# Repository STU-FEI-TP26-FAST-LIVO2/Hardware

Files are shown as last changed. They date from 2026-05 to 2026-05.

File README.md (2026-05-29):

# TP-Hardware

[Repo link](https://github.com/STU-FEI-TP26-FAST-LIVO2/Hardware-Mechanical)

> SK Verzia

Mechanická časť hardvéru<br>
[Datasheets](parameters_datasheets/)<br>
[.step súbory](printable/step/)<br>
[.stl súbory](printable/stl/)<br>
[Technické výkresy](technical_drawings/)<br>

# 3D modely konštrukčných dielov

Kompletný zoznam konštrukčných častí je uvedený nižšie. Príslušné technické výkresy sú pripojené ku každému komponentu.
Všetky rozmery potrebné k návrhu konštrukčných dielov boli prevzaté z údajových listov jednotlivých komponentov, ktoré sú uložené [tu](parameters_datasheets/).
[LiDAR](https://www.hesaitech.com/wp-content/uploads/2025/04/PandarXT-16_User_Manual_X02-en-250410.pdf)
[Kamera](https://docs.baslerweb.com/a2a1920-160ucpro)
[IMU](https://product.tdk.com/system/files/dam/doc/product/sensor/mortion-inertial/imu/data_sheet/ds-000330_icm-40609-d_v1.2.pdf)
[Jetson download center](https://developer.nvidia.com/embedded/downloads#?tx=$product,jetson_agx_orin)

## sensors_module_top

[Technický výkres](technical_drawings/sensors_modul_top_drawing.pdf)

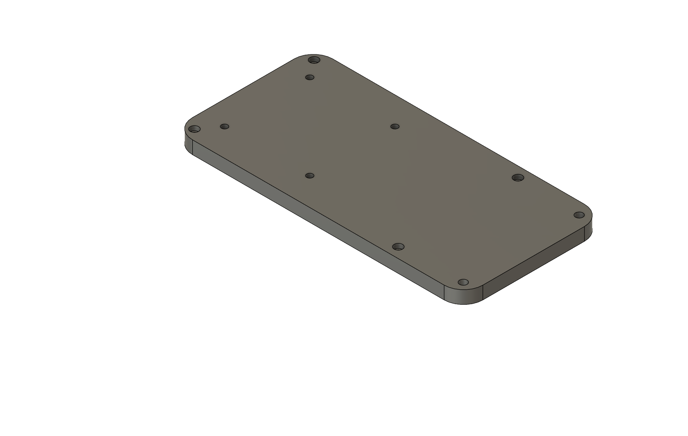
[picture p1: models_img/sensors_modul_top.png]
sensors_module_top


## sensors_module_bottom

[Technický výkres](technical_drawings/sensors_module_bottom_drawing.pdf)

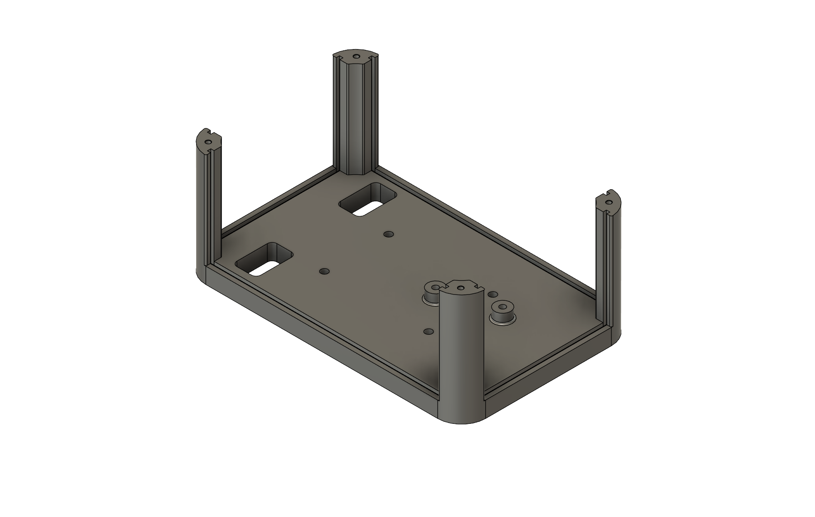
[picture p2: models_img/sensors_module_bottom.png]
sensors_module_bottom


## sm_wall_back

[Technický výkres](technical_drawings/sm_wall_back_drawing.pdf)

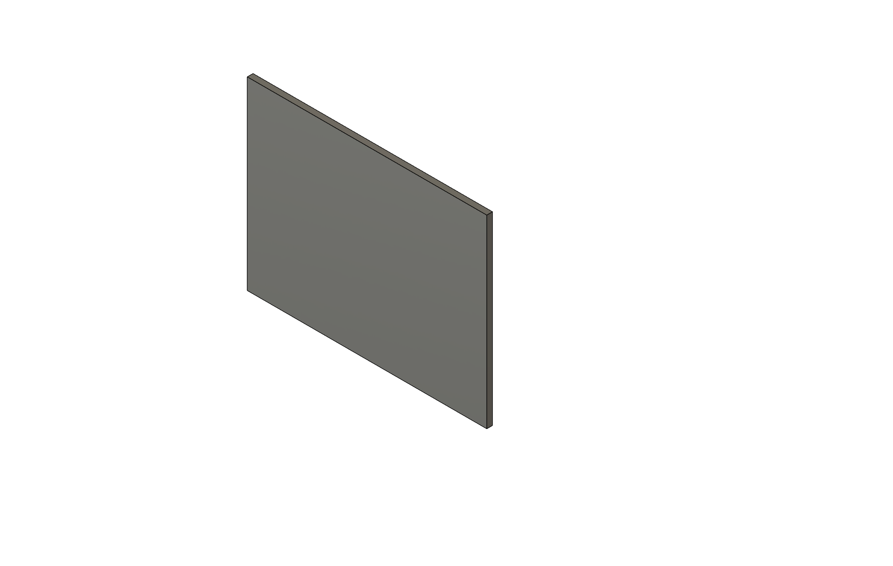
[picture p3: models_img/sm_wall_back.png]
sm_wall_back


## sm_wall_front

[Technický výkres](technical_drawings/sm_wall_front_drawing.pdf)

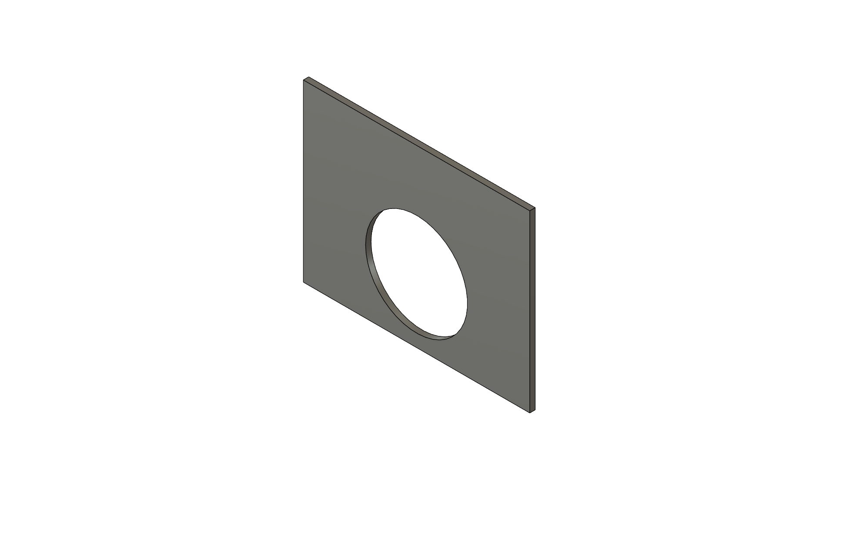
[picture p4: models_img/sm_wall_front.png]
sm_wall_front


## sm_wall_side

[Technický výkres](technical_drawings/sm_wall_side_drawing.pdf)

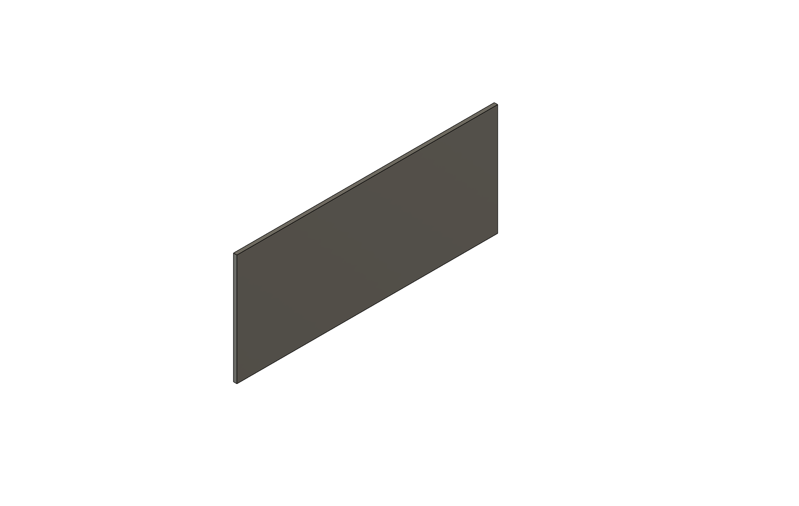
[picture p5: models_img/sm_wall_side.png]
sm_wall_side


## acu_jetson_case

[Technický výkres](technical_drawings/acu_jetson_case_drawing.pdf)

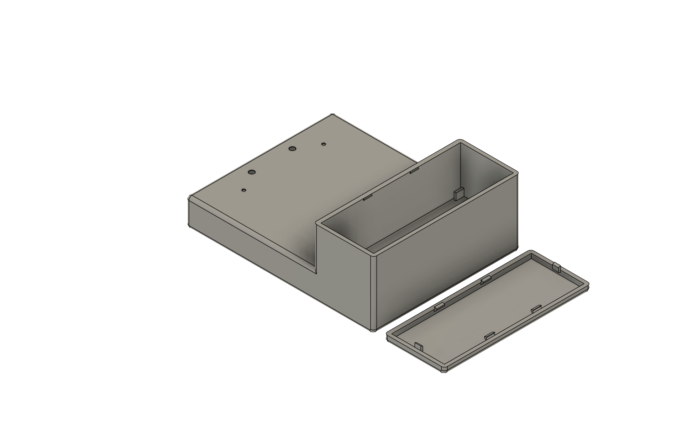
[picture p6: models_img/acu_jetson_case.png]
acu_jetson_case


## handles

[Technický výkres](technical_drawings/handles_drawing.pdf)

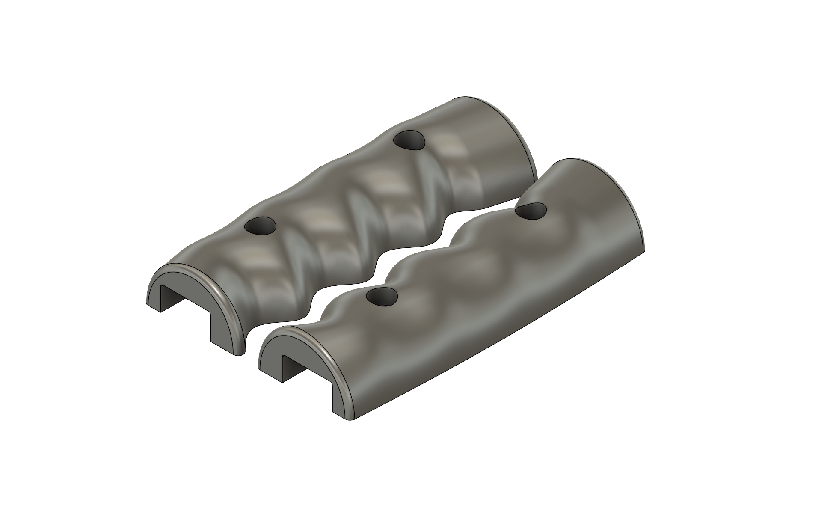
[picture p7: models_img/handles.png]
handles


# Spojovací materiál — Zoznam

| #  | Spojovací materiál | Typ | Počet |
| -- | --- | --- | ----- |
| 1  | Zápustná skrutka JIS B 1111 - M5x6 - H Steel 4.6 Plain | Skrutka | 8 |
| 2  | Zápustná skrutka JIS B 1111 - M5x30 H Steel 4.6 Plain | Skrutka | 4 |
| 3  | Šesťhranná matica DIN 934 - M5 x 0.8 Steel 6 Plain | Matica  | 8 |
| 4  | Zápustná skrutka JIS B 1111 - M5x20 H Steel 4.6 Plain | Skrutka | 4 |
| 5  | Skrutka s valcovou hlavou a vnútorným šesťhranom DIN 912 - M5 x 0.8 x 6 Steel 4.6 Plain  | Skrutka | 4 |
| 6  | Skrutka s valcovou hlavou a vnútorným šesťhranom DIN 912 - M3 x 0.5 x 10 Steel 4.6 Plain | Skrutka | 7 |
| 7  | Skrutka s valcovou hlavou a vnútorným šesťhranom DIN 912 - M3 x 0.5 x 12 Steel 4.6 Plain | Skrutka | 4 |
| 8  | Skrutka s valcovou hlavou a vnútorným šesťhranom DIN 912 - M4 x 0.7 x 16 Steel 4.6 Plain | Skrutka | 4 |
| 9  | Šesťhranná matica DIN 934 - M2.5 x 0.45 | Matica  | 8 |
| 10 | Závitová tyč DIN 976-1 - M2.5 x 85 - A | Stĺpik  | 4 |
| 11 | Závitový čap DIN 938 - M3 x 30 Steel 4.6 Plain/M2.5 | Stĺpik  | 4 |
| 12 | Šesťhranná matica DIN EN 24032 - M3 Steel 6 Plain | Matica  | 4 |
| 13 | DIN 912 - M5 x 0.8 x 10 Steel 4.6 Plain | Skrutka | 2 |
| 14 | T-matica M5 | Matica  | 8 |

**Celkový počet spojovacích prvkov: 73**

## Súhrn podľa častí, ktoré sú spojené

### Nosná konštrukcia (alu_profile / alu_profile_Lko)

| Spojovací materiál | Typ | Počet | Spája |
| --- | --- | ----- | --- |
| Zápustná skrutka JIS B 1111 - M5x6 | Skrutka | 8 | alu_profile_Lko ↔ alu_profile cez kamienok_profile |

### Senzorový modul (sensors_module_bottom / sm_wall_back / sm_wall_front / sm_wall_back / sensors_modul_top)

| Spojovací materiál | Typ | Počet | Spája |
| --- | --- | ----- | --- |
| Skrutka s vnútorným šesťhranom DIN 912 - M3x12 | Skrutka | 4 | sensors_module_bottom_v2 ↔ sensors_module_top |
| Skrutka s vnútorným šesťhranom DIN 912 - M3x10 | Skrutka | 4 | PCB_with_IMU ↔ sensors_modul_top_v3 |
| Skrutka s vnútorným šesťhranom DIN 912 - M3x10 | Skrutka | 3 | camera ↔ sensors_module_bottom_v2 |
| Zápustná skrutka JIS B 1111 - M5x20 | Skrutka | 4 | sensors_module_bottom_v2 ↔ alu_profile_Lko |
| Šesťhranná matica DIN 934 - M5 x 0.8 | Matica  | 4 | Použité s vyššie uvedenými M5 skrutkami |
| Skrutka s vnútorným šesťhranom DIN 912 - M4x16 | Skrutka | 4 | LiDAR ↔ sensors_module_top |

### Baterka / Jetson modul (acu_jetson_case)

| Spojovací materiál | Typ | Počet | Spája |
| --- | --- | ----- | --- |
| Zápustná skrutka JIS B 1111 - M5x30 | Skrutka | 4 | alu_profile_Lko ↔ acu_jetson_case |
| Šesťhranná matica DIN 934 - M5 x 0.8 | Matica  | 4 | Použité s vyššie uvedenými M5 skrutkami  |
| Závitová tyč DIN 976-1 - M2.5 x 85 - A  | Stĺpik  | 4 | acu_jetson_case ↔ jetson_agx_orin_model  |
| Šesťhranná matica DIN 934 - M2.5 x 0.45 | Matica  | 8 | acu_jetson_case & vyššie uvedené stĺpiky |

### Rukoväte

| Spojovací materiál | Typ | Počet | Spája |
| --- | --- | ----- | --- |
| Skrutka s vnútorným šesťhranom DIN 912 - M5x6 | Skrutka | 4 | handles ↔ alu_profile |

### Jetson AGX Orin Podzostava (jetson_agx_orin_model)

| Spojovací materiál | Typ | Počet | Spája |
| --- | --- | ----- | --- |
| Závitový čap DIN 938 - M3x30 | Stĺpik | 4 | jetson_agx_orin_model ↔ stlpik (stĺpiky) |
| Šesťhranná matica DIN EN 24032 - M3 | Matica | 4 | Párované s M3 stĺpikmi → uchytenie stĺpika |

### Komunikačné rozhranie LiDARu

| Spojovací materiál | Typ | Počet | Spája |
| --- | --- | ----- | --- |
| DIN 912 - M5 x 0.8 x 10 Steel 4.6 Plain | Skrutka | 2 | connection_box ↔ sensors_module_top |

# Extrinzické kalibrácie senzorov

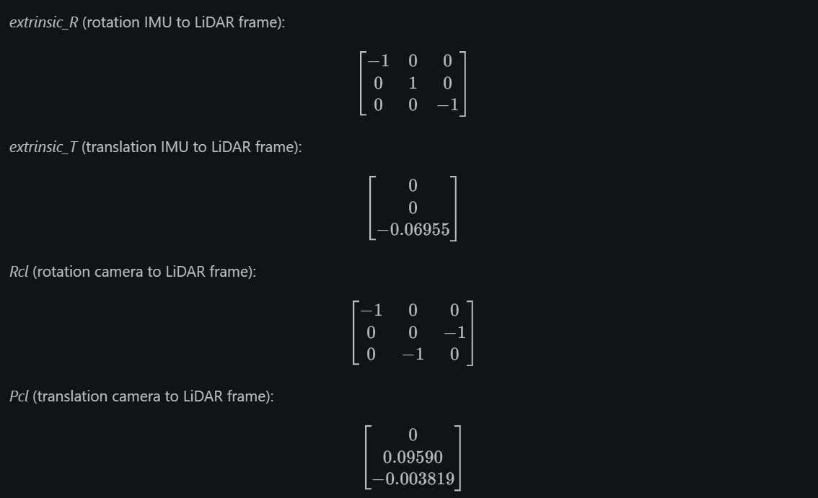
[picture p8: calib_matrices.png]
calib


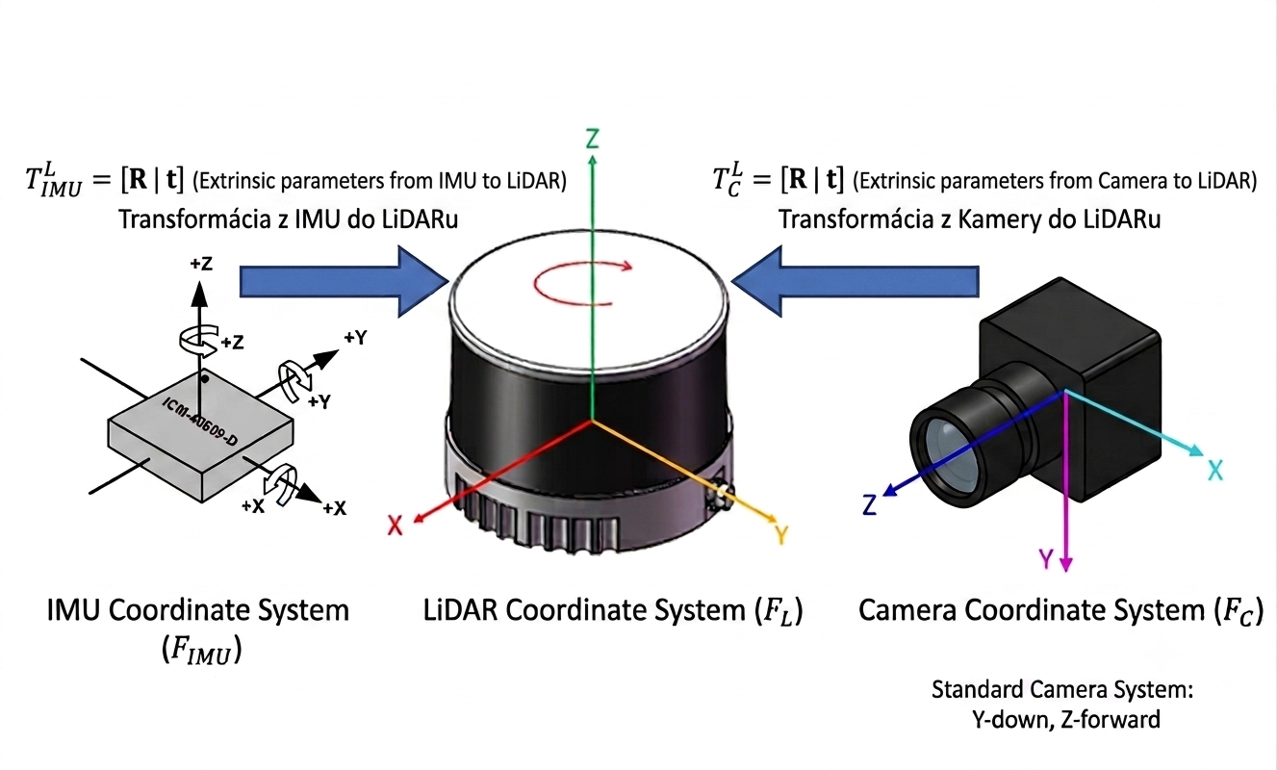
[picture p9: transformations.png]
sensoric transformations transformations


# Kompletná Zostava

## Konštrukčné časti:

* `acu_jetson_case` - modul pre Jetson a batériu
* `handles` - rukoväte pre jednoduché uchopenie
* `alu_profile` - nosná časť celej konštrukcie
* `alu_profile_Lko` - L držiak
* `sensors_module_bottom` - spodná časť senzorového modulu
* `sensors_module_top` - horná časť senzorového modulu
* `sm_wall_side` x2, `sm_wall_back`, `sm_wall_front` - steny senzorového modulu s estetickou funkciou
* `alu_profile2` x2 - stojan senzorového modulu

## Elektrické komponenty:

* LiDAR Hesai XT16
* IMU ICM-40609-D
* Kamera Basler a2A 1920 - 160uc PRO so 6 mm C-mount objektívom
* Jetson AGX Orin 64GB Developer Kit
* Acu Amewi Li-Pol 5500mAh/14,8V
* STM32 F103 Bluepill
* TTL/RS232 prevodník

## Izometrický pohľad kompletnej zostavy

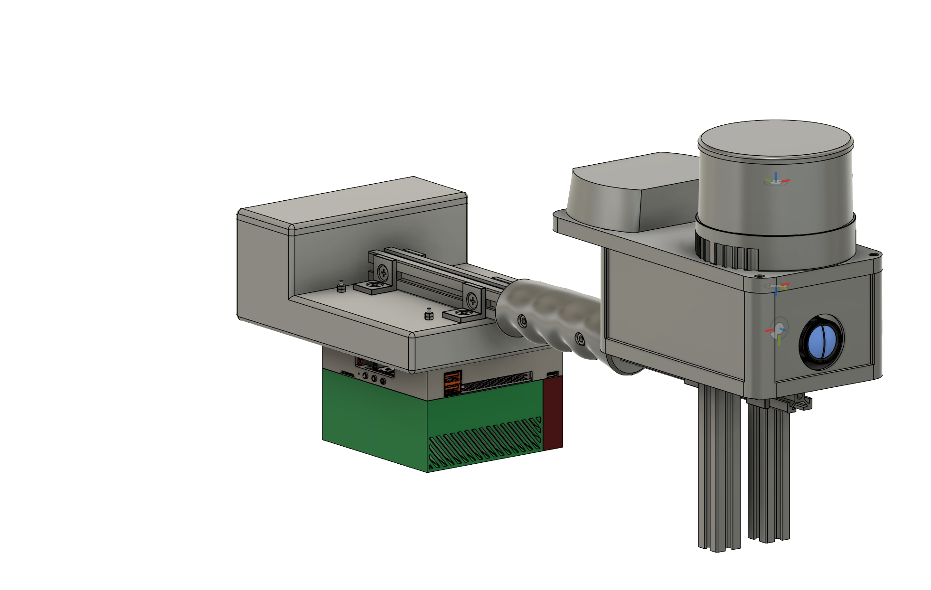
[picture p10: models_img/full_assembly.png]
full_assembly


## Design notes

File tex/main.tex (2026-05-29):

%-----------------------------------------------------------
Moja práca na hardvérovej časti tímového projektu -- návrh
\textit{mechanickej konštrukcie} a \textit{geometrický vzťah medzi
referenčnými rámcami senzorov}

%-----------------------------------------------------------
\section{Hardvérové komponenty a ich úloha}
Platforma integruje tri senzorické zariadenia, výpočtovú jednotku, a~mikroelektroniku
zabezpečujúcu komunikáciu, mechanicky zviazané do
jedného tuhého celku pomocou hliníkového profilu a~3D-tlačených konštrukčných dielov:

\begin{itemize}
  \item \textbf{LiDAR Hesai XT16} -- primárny zdroj 3D geometrie scény (16~kanálov,
        rotujúci skener). Definuje hlavný (referenčný) súradnicový systém modulu, do
        ktorého sú ostatné senzory kalibrované.
  \item \textbf{IMU ICM-40609-D} -- 6-DoF inerciálna jednotka so známym počiatkom súradnicovej sústavy
        (akcelerometrický origin). Slúži na určenie orientácie a~pomáha pri
        synchronizácii LiDAR-ových mračien bodov.
  \item \textbf{Kamera Basler a2A 1920 - 160uc PRO} so~6\,mm C-mount objektívom -- vizuálny kanál
        pre fúziu s~LiDAR-om (textúra a ofarbenie mračna bodov).
  \item \textbf{Jetson AGX Orin 64GB} -- výpočtová jednotka, mechanicky odsadená od
        senzorického modulu (vlastný 3D-tlačený box).
  \item \textbf{Akumulátor Amewi Li-Pol 5500mAh/14,8V} -- umiestnená v boxe s~GPU, napája GPU a LiDAR.
  \item \textbf{STM32 F103 Bluepill} -- mikrokontrolér pre synchronizáciu a komunikáciu senzorov
  \item \textbf{TTL/RS232 prevodník} -- zabezpečuje komunikáciu mikrokontroléra s LiDARom

\end{itemize}

Nosnou kostrou je hliníkový profil spájaný drážkovými T-maticami a~zápustnými skrutkami M5.

%-----------------------------------------------------------
\section{3D modely a~mechanická koncepcia}
Konštrukcia bola navrhnutá tak, aby minimalizovala neurčitosti v~polohách senzorov
a~ostala vyrobiteľná na bežnej FDM tlačiarni. Senzorický modul je tvorený dvoma hlavnými dielmi:
spodná konzola s~kamerou a kotvením na profil a~vrchná časť s~otvormi pre LiDAR a jeho komunikačný box.
Bočnice (steny) uzatvárajú modul. GPU spolu s baterkou sú umiestnené v~oddelenom
boxe, ktorý je uchytený L konzolami k hliníkovému profilu, čo umožňuje
servis bez rozoberania senzorickej hlavy. \textbf{Všetky tlačené súčiastky sú z materiálu PLA}.

\begin{figure}[H]
  \centering
  % --- MIESTO PRE OBRÁZOK 1: finálna konštrukcia ---
  
  \caption{Finálna konštrukcia}
  \label{fig:assembly}
\end{figure}

Kľúčové dizajnové rozhodnutia: (i) LiDAR nad kamerou s~vertikálnym odsadením,
aby si zorné polia navzájom neclonili; (ii) IMU pripevnená na vrchnej časti senzorického modulu -- fixný
vzťah IMU--LiDAR bez pohyblivých spojení; (iii) Jetson v~samostatnom boxe mimo senzorickej
hlavy.

%-----------------------------------------------------------
\section{Transformácie medzi súradnicovými systémami}
Pre fúziu dát musí byť každé meranie
prevedené do jedného referenčného rámca -- zvolili sme \emph{LiDAR-rámec} $\mathcal{F}_L$.

\begin{figure}[H]
  \centering
  % --- MIESTO PRE OBRÁZOK 2: schéma transformácií medzi senzormi ---
  
  \caption{Transformácie medzi rámcami kamery~$\mathcal{F}_C$, IMU~$\mathcal{F}_I$
  a~LiDAR-u~$\mathcal{F}_L$.}
  \label{fig:transforms}
\end{figure}

\paragraph{IMU $\rightarrow$ LiDAR}
\[
\mathbf{R}_{LI}=\!\begin{bmatrix}-1 & 0 & 0\\ 0 & 1 & 0\\ 0 & 0 & -1\end{bmatrix}\!,
\qquad
\mathbf{t}_{LI}=\!\begin{bmatrix}0\\ 0\\ -0{,}06955\end{bmatrix}\!\text{m}.
\]
Rotácia zodpovedá otočeniu o~$180^\circ$ okolo osi~$y$ (IMU je voči LiDAR-u prevrátený
zhora-nadol). Posun je iba vo vertikále -- IMU sa nachádza pribl. 70\,mm pod
referenčným bodom LiDAR-u.

\paragraph{Kamera $\rightarrow$ LiDAR}
\[
\mathbf{R}_{LC}=\!\begin{bmatrix}-1 & 0 & 0\\ 0 & 0 & -1\\ 0 & -1 & 0\end{bmatrix}\!,
\qquad
\mathbf{t}_{LC}=\!\begin{bmatrix}0\\ 0{,}09590\\ -0{,}00382\end{bmatrix}\!\text{m}.
\]
$\mathbf{R}_{LC}$ rotuje rámec kamery na rámec LiDAR-u ($x_C\!\to\!-x_L$, $z_C\!\to\!-y_L$,
$y_C\!\to\!-z_L$); kamera je odsadená pribl. 96\,mm v osi y a~mierne posunutá o -3.819 mm v osi z.

%-----------------------------------------------------------
\section{Záver}
Výsledkom je tuhá modulárna konštrukcia geometricky fixujúca LiDAR, kameru a~IMU s~jasne
definovanou extrinsikou. Transformačné matice vychádzajú z~CAD geometrie a~vstupujú do senzorickej
fúzie.

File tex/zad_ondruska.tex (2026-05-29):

\documentclass{FEIstyle}
\usepackage{booktabs}
\usepackage{graphicx}
\usepackage{subcaption}
\usepackage{amsmath}
\usepackage{listings}
\usepackage{xcolor}

\lstset{
    language=Matlab,
    basicstyle=\ttfamily\small,
    keywordstyle=\color{blue},
    commentstyle=\color{green!60!black},
    stringstyle=\color{red},
    breaklines=true,
    frame=single
}

\addbibresource{inc/ref.bib}
\FEIauthor{Bc. Matúš Ondruška}

\FEItitle{Výstupná správa do dokumentácie}

\FEIpredmet{Tímový projekt}

\FEIdate{2025/2026}

\begin{document}

% \frontmatter

\FEIcover
\FEIcontent

\mainmatter

\include{main.tex}

% \backmatter

%% Attachment A
%\FEIappendix{Algoritmus\label{att:algorithms}}{includes/attachmentA}

\FEIbibliography
\end{document}

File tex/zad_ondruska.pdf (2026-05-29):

### SLOVENSKÁ TECHNICKÁ UNIVERZITA V BRATISLAVE

### Fakulta elektrotechniky a informatiky

# Výstupná správa do dokumentácie

### Tímový projekt

2025/2026 | Bc. Matúš Ondruška

## Obsah

1 Hardvérové komponenty a ich úloha | 3
2 3D modely a mechanická koncepcia | 3
3 Transformácie medzi súradnicovými systémami | 4
4 Záver | 5

Moja práca na hardvérovej časti tímového projektu – návrh mechanickej konštrukcie a geometrický vzťah medzi referenčnými rámcami senzorov

# 1 Hardvérové komponenty a ich úloha

Platforma integruje tri senzorické zariadenia, výpočtovú jednotku, a mikroelektroniku zabezpečujúcu komunikáciu, mechanicky zviazané do jedného tuhého celku pomocou hliníkového profilu a 3D-tlačených konštrukčných dielov:

- LiDAR Hesai XT16 – primárny zdroj 3D geometrie scény (16 kanálov, rotujúci skener). Definuje hlavný (referenčný) súradnicový systém modulu, do ktorého sú

ostatné senzory kalibrované.

- IMU ICM-40609-D – 6-DoF inerciálna jednotka so známym počiatkom súradnicovej sústavy (akcelerometrický origin). Slúži na určenie orientácie a pomáha

pri synchronizácii LiDAR-ových mračien bodov.

- Kamera Basler a2A 1920 - 160uc PRO so 6 mm C-mount objektívom – vizuálny kanál pre fúziu s LiDAR-om (textúra a ofarbenie mračna bodov).
- Jetson AGX Orin 64GB – výpočtová jednotka, mechanicky odsadená od senzorického modulu (vlastný 3D-tlačený box).
- Akumulátor Amewi Li-Pol 5500mAh/14,8V – umiestnená v boxe s GPU,

napája GPU a LiDAR.

- STM32 F103 Bluepill – mikrokontrolér pre synchronizáciu a komunikáciu senzorov
- TTL/RS232 prevodník – zabezpečuje komunikáciu mikrokontroléra s LiDARom

Nosnou kostrou je hliníkový profil spájaný drážkovými T-maticami a zápustnými skrutkami M5.

# 2 3D modely a mechanická koncepcia

Konštrukcia bola navrhnutá tak, aby minimalizovala neurčitosti v polohách senzorov a ostala vyrobiteľná na bežnej FDM tlačiarni. Senzorický modul je tvorený dvoma hlavnými dielmi: spodná konzola s kamerou a kotvením na profil a vrchná časť s otvormi pre LiDAR a jeho komunikačný box. Bočnice (steny) uzatvárajú modul. GPU spolu s baterkou sú umiestnené v oddelenom boxe, ktorý je uchytený L konzolami k hliníkovému profilu, čo umožňuje servis bez rozoberania senzorickej hlavy. Všetky tlačené súčiastky sú z materiálu PLA.

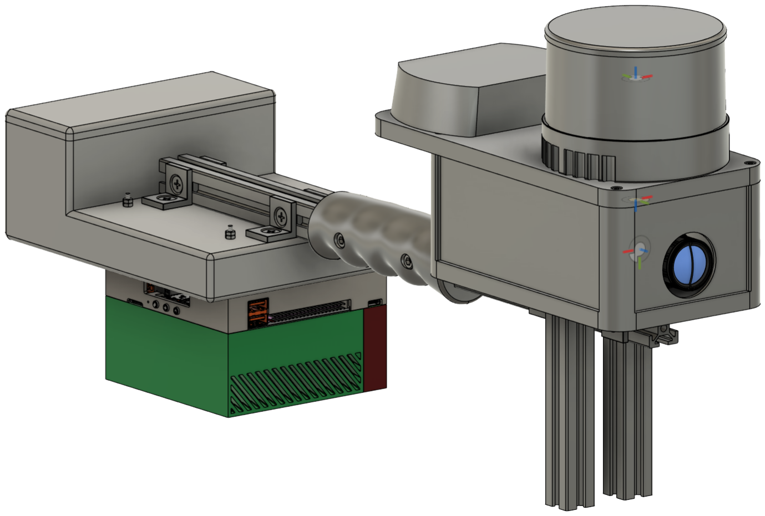
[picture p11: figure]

Obr. 1: Finálna konštrukcia

Kľúčové dizajnové rozhodnutia: (i) LiDAR nad kamerou s vertikálnym odsadením, aby si zorné polia navzájom neclonili; (ii) IMU pripevnená na vrchnej časti senzorického modulu – fixný vzťah IMU–LiDAR bez pohyblivých spojení; (iii) Jetson v samostatnom

boxe mimo senzorickej hlavy.

# 3 Transformácie medzi súradnicovými systémami

Pre fúziu dát musí byť každé meranie prevedené do jedného referenčného rámca – zvolili sme LiDAR-rámec FL.

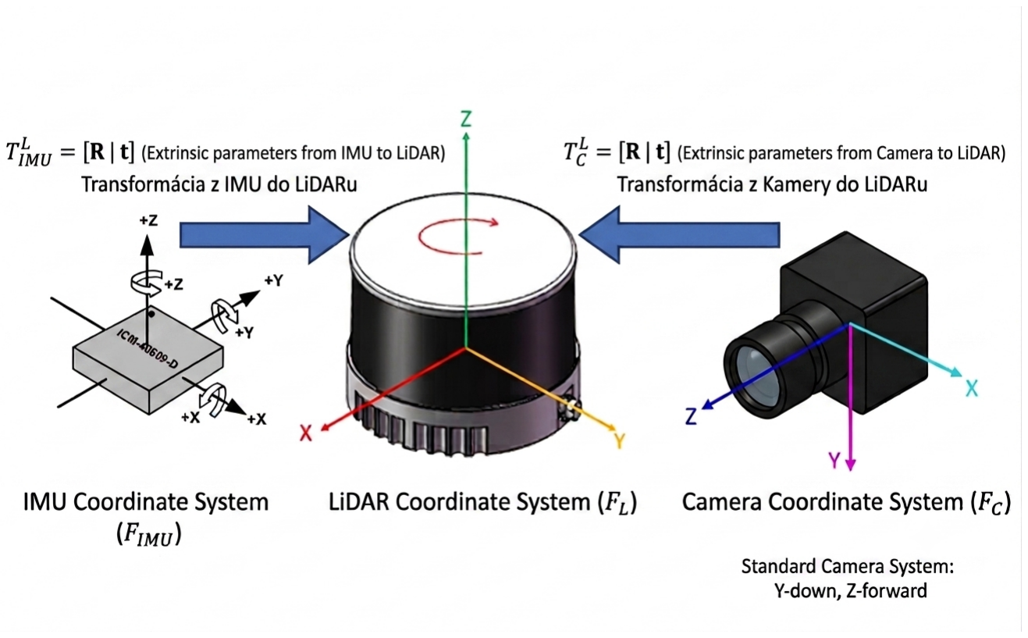
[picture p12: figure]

Obr. 2: Transformácie medzi rámcami kamery FC, IMU FI a LiDAR-u FL.

IMU → LiDAR

RLI =

−1 0 | 0
0 | 1 | 0
0 | 0 −1

, tLI =

0
0
−0,06955

m.

Rotácia zodpovedá otočeniu o 180◦ okolo osi y (IMU je voči LiDAR-u prevrátený zhora-

-nadol). Posun je iba vo vertikále – IMU sa nachádza pribl. 70 mm pod referenčným

bodom LiDAR-u.

Kamera → LiDAR

RLC =

−1 | 0 | 0
0 | 0 | −1
0 | −1 | 0

, tLC =

0
0,09590
−0,00382

m.

RLC rotuje rámec kamery na rámec LiDAR-u (xC → −xL, zC → −yL, yC → −zL);

kamera je odsadená pribl. 96 mm v osi y a mierne posunutá o -3.819 mm v osi z.

# 4 Záver

Výsledkom je tuhá modulárna konštrukcia geometricky fixujúca LiDAR, kameru a IMU s jasne definovanou extrinsikou. Transformačné matice vychádzajú z CAD geometrie a vstupujú do senzorickej fúzie.

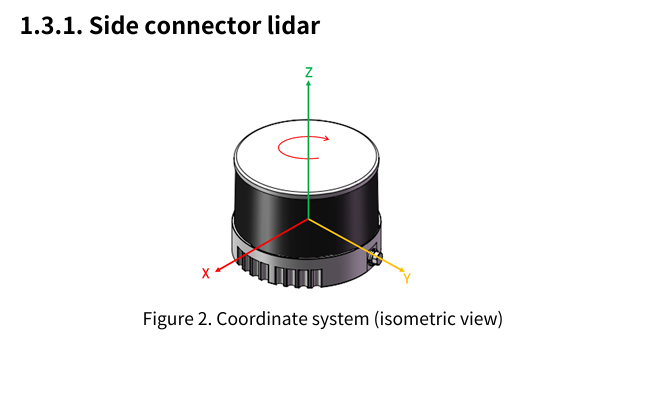
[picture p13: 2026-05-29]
parameters_datasheets/Hesai_XT16_coordinate_system.png

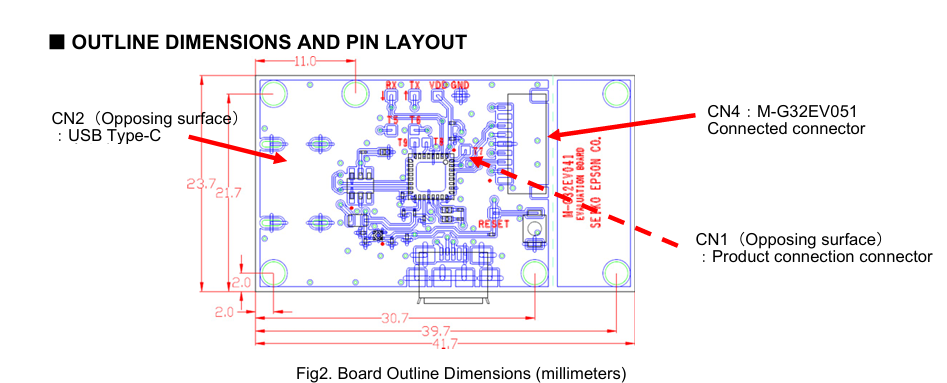
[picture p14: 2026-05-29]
parameters_datasheets/IMU_board_dimensions.png

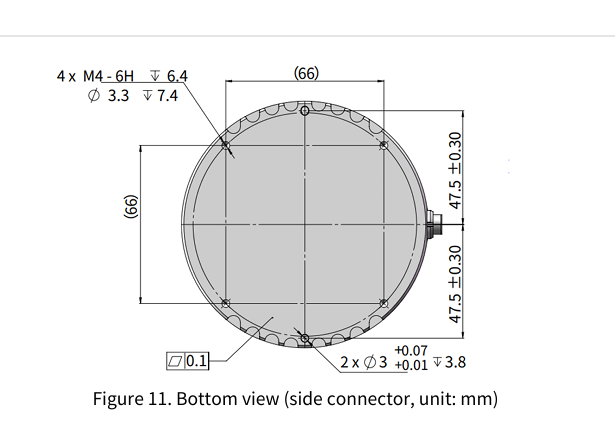
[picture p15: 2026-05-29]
parameters_datasheets/Hesai_XT16_mounting_holes.png

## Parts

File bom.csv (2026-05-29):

Part Name | full_assembly
Working BOM | as of May 4, 2026 at 11:23:04 AM UTC
Exported by | xondruskam@stuba.sk
Time of Export | 11:23 AM May 4, 2026
 | Part Number | Part Name | Revision/Version | Description | Item Number | Lifecycle | Revision | State | Quantity | Material | Change Order
 | 2026-04-16-22-42-03-118 | full_assembly |  |  |  |  |  | Working | 1
1 | 2026-04-16-22-42-56-429 | alu_profile |  |  |  |  |  | Working | 1 | Steel
2 | 2026-04-14-16-02-33-037 | handles1 |  |  |  |  |  | Working | 18 | Steel
3 | 2026-03-15-10-35-25-822 | sensors_module_bottom |  |  |  |  |  | Working | 18 | Steel
4 | DIN 934 - M5 x 0.8 Steel 6 Plain | Hexagon Nut DIN 934 - M5 x 0.8 Steel 6 Plain |  | Hexagon Nut DIN 934 - M5 x 0.8 |  |  |  | Working | 62 | Steel 6, Plain
5 | 2026-03-09-20-47-32-778 | Basler Lens 6mm C-Mount v02 |  |  |  |  |  | Working | 1 | Steel
6 | 2026-03-09-20-34-58-537 | Basler ace2 USB3 |  |  |  |  |  | Working | 18 | Generisch
7 | 2026-04-09-10-57-03-371 | sm_wall_side |  |  |  |  |  | Working | 2 | Steel
8 | 2026-04-09-10-55-33-947 | sm_wall_back |  |  |  |  |  | Working | 19 | Steel
9 | 2026-03-14-23-06-42-400 | sensors_modul_top |  |  |  |  |  | Working | 1 | Steel
10 | 2026-03-08-14-38-50-925 | Lidar |  |  |  |  |  | Working | 1 | Steel
11 | DIN 912 - M4 x 0.7 x 16 Steel 4.6 Plain | Hexagon Socket Head Cap Screw DIN 912 - M4 x 0.7 x 16 Steel 4.6 Plain |  | Hexagon Socket Head Cap Screw DIN 912 - M4 x 0.7 x 16 |  |  |  | Working | 55 | Steel 4.6, Plain
12 | DIN 912 - M3 x 0.5 x 10 Steel 4.6 Plain | Hexagon Socket Head Cap Screw DIN 912 - M3 x 0.5 x 10 Steel 4.6 Plain |  | Hexagon Socket Head Cap Screw DIN 912 - M3 x 0.5 x 10 |  |  |  | Working | 93 | Steel 4.6, Plain
13 | 2026-03-24-17-37-45-235 | BreadBord.step |  |  |  |  |  | Working | 5
13.1 | 2026-03-25-18-53-00-214 | Component1 |  |  |  |  |  | Working | 1 | Steel
13.2 | 2026-03-25-18-53-00-219 | Component2 |  |  |  |  |  | Working | 1 | Steel
14 | 2026-03-16-16-32-24-828 | 6DOF_IMU_24_Click_v100 |  | Open CASCADE Model |  |  |  | Working | 1
14.1 | 2026-03-25-19-01-00-205 | Component37 |  |  |  |  |  | Working | 1 | Steel
15 | 2026-04-24-12-49-05-410 | acu_jetson_case |  |  |  |  |  | Working | 1
15.1 | 2026-04-19-15-53-45-452 | acu |  |  |  |  |  | Working | 1 | Steel
16 | 2026-04-24-19-06-08-831 | alu_profile_Lko |  |  |  |  |  | Working | 59 | Steel
17 | CS JIS B 1111 - M5x30 - H Steel 4.6 Plain | Countersunk Screw JIS B 1111 - M5x30 H Steel 4.6 Plain |  | Countersunk Screw JIS B 1111 - M5x30 H |  |  |  | Working | 55 | Steel 4.6, Plain
18 | CS JIS B 1111 - M5x20 - H Steel 4.6 Plain | Countersunk Screw JIS B 1111 - M5x20 H Steel 4.6 Plain |  | Countersunk Screw JIS B 1111 - M5x20 H |  |  |  | Working | 55 | Steel 4.6, Plain
19 | 2026-04-26-18-56-57-064 | podstavec |  |  |  |  |  | Working | 18 | Steel
20 | 2026-04-16-22-15-38-131 | jetson_agx_orin_model |  |  |  |  |  | Working | 16
20.1 | 2026-04-16-22-15-38-141 | 600-13737-0000-A01_ASM |  | NOT SPECIFIED |  |  |  | Working | 1
20.1.1 | 2026-04-16-22-15-38-152 | LOGO_LABEL_PPID_0180X0050 |  | NOT SPECIFIED |  |  |  | Working | 1 | PTC_SYSTEM_MTRL_PROPS
20.1.2 | 2026-04-16-22-15-38-257 | 080-1638-000_2 |  | NOT SPECIFIED |  |  |  | Working | 1 | AL6061
20.1.3 | 2026-04-16-22-15-38-283 | 091-0023-000_1 |  | NOT SPECIFIED |  |  |  | Working | 1 | PTC_SYSTEM_MTRL_PROPS
20.1.4 | 2026-04-16-22-15-38-261 | 080-1665-000_1 |  | NOT SPECIFIED |  |  |  | Working | 1 | PTC_SYSTEM_MTRL_PROPS
20.1.5 | 2026-04-16-22-15-38-225 | 130-0938-000_1 |  | NOT SPECIFIED |  |  |  | Working | 1 | PTC_SYSTEM_MTRL_PROPS
20.1.6 | 2026-04-16-22-15-38-280 | 300-0494-000_1 |  | NOT SPECIFIED |  |  |  | Working | 1 | PTC_SYSTEM_MTRL_PROPS
20.1.7 | 2026-04-16-22-15-38-307 | 032-0696-000_1 |  | NOT SPECIFIED |  |  |  | Working | 4 | PTC_SYSTEM_MTRL_PROPS
20.1.8 | 2026-04-16-22-15-38-231 | 115-2921-000_1 |  | NOT SPECIFIED |  |  |  | Working | 1 | PTC_SYSTEM_MTRL_PROPS
20.1.9 | 2026-04-16-22-15-38-213 | 080-1931-000_2 |  | NOT SPECIFIED |  |  |  | Working | 2 | PTC_SYSTEM_MTRL_PROPS
20.1.10 | 2026-04-16-22-15-38-264 | 300-0402-000_1 |  | NOT SPECIFIED |  |  |  | Working | 6 | PTC_SYSTEM_MTRL_PROPS
20.1.11 | 2026-04-16-22-15-38-252 | 041-0196-000_1 |  | NOT SPECIFIED |  |  |  | Working | 2 | PTC_SYSTEM_MTRL_PROPS
20.1.12 | 2026-04-16-22-15-38-260 | 300-1096-000_1 |  | NOT SPECIFIED |  |  |  | Working | 3 | AL6061
20.1.13 | 2026-04-16-22-15-38-275 | 115-1345-000_4 |  | NOT SPECIFIED |  |  |  | Working | 3 | PTC_SYSTEM_MTRL_PROPS
20.1.14 | 2026-04-16-22-15-38-207 | 115-2489-000_1 |  | NOT SPECIFIED |  |  |  | Working | 2 | PTC_SYSTEM_MTRL_PROPS
20.1.15 | 2026-04-16-22-15-38-210 | 320-1005-000_1 |  | NOT SPECIFIED |  |  |  | Working | 4 | AL6061
20.1.16 | 2026-04-16-22-15-38-304 | 300-1070-000_3 |  | NOT SPECIFIED |  |  |  | Working | 4 | PTC_SYSTEM_MTRL_PROPS
20.1.17 | 2026-04-16-22-15-38-221 | 090-0377-000_1 |  | NOT SPECIFIED |  |  |  | Working | 1 | PTC_SYSTEM_MTRL_PROPS
20.1.18 | 2026-04-16-22-15-38-289 | 0603_H060 |  | NOT SPECIFIED |  |  |  | Working | 5 | PTC_SYSTEM_MTRL_PROPS
20.1.19 | 2026-04-16-22-15-38-222 | 080-1924-000_1 |  | NOT SPECIFIED |  |  |  | Working | 1 | PTC_SYSTEM_MTRL_PROPS
20.1.20 | 2026-04-16-22-15-38-234 | 090-0102-000_2 |  | NOT SPECIFIED |  |  |  | Working | 5 | PTC_SYSTEM_MTRL_PROPS
20.1.21 | 2026-04-16-22-15-38-216 | 080-1690-000_2 |  | NOT SPECIFIED |  |  |  | Working | 1 | PTC_SYSTEM_MTRL_PROPS
20.1.22 | 2026-04-16-22-15-38-319 | VSB_071C125D |  | NOT SPECIFIED |  |  |  | Working | 14 | PTC_SYSTEM_MTRL_PROPS
20.1.23 | 2026-04-16-22-15-38-240 | 174-0159-000_2 |  | NOT SPECIFIED |  |  |  | Working | 1 | PTC_SYSTEM_MTRL_PROPS
20.1.24 | 2026-04-16-22-15-38-249 | 0805_H140 |  | NOT SPECIFIED |  |  |  | Working | 2 | PTC_SYSTEM_MTRL_PROPS
20.1.25 | 2026-04-16-22-15-38-282 | 091-0022-000_1 |  | NOT SPECIFIED |  |  |  | Working | 2 | PTC_SYSTEM_MTRL_PROPS
20.1.26 | 2026-04-16-22-15-38-241 | IND_SMD_0402_H060 |  | NOT SPECIFIED |  |  |  | Working | 2 | PTC_SYSTEM_MTRL_PROPS
20.1.27 | 2026-04-16-22-15-38-284 | 0402_H040 |  | NOT SPECIFIED |  |  |  | Working | 427 | PTC_SYSTEM_MTRL_PROPS
20.1.28 | 2026-04-16-22-15-38-238 | 090-0296-000_2 |  | NOT SPECIFIED |  |  |  | Working | 17 | PTC_SYSTEM_MTRL_PROPS
20.1.29 | 2026-04-16-22-15-38-271 | 316-0924-000_1 |  | NOT SPECIFIED |  |  |  | Working | 1 | PTC_SYSTEM_MTRL_PROPS
20.1.30 | 2026-04-16-22-15-38-287 | 0603_H100 |  | NOT SPECIFIED |  |  |  | Working | 77 | PTC_SYSTEM_MTRL_PROPS
20.1.31 | 2026-04-16-22-15-38-296 | 115-0655-000_3 |  | NOT SPECIFIED |  |  |  | Working | 1 | PTC_SYSTEM_MTRL_PROPS
20.1.32 | 2026-04-16-22-15-38-208 | 115-3085-000_1 |  | NOT SPECIFIED |  |  |  | Working | 1 | PTC_SYSTEM_MTRL_PROPS
20.1.33 | 2026-04-16-22-15-38-258 | QFN020Q_P050_0030_T018X018 |  | NOT SPECIFIED |  |  |  | Working | 1 | AL6061
20.1.34 | 2026-04-16-22-15-38-266 | 115-2500-000_2 |  | NOT SPECIFIED |  |  |  | Working | 1 | PTC_SYSTEM_MTRL_PROPS
20.1.35 | 2026-04-16-22-15-38-219 | DFN08_P050_020X030_T016X002 |  | NOT SPECIFIED |  |  |  | Working | 1 | AL6061
20.1.36 | 2026-04-16-22-15-38-285 | 0402_H060 |  | NOT SPECIFIED |  |  |  | Working | 276 | PTC_SYSTEM_MTRL_PROPS
20.1.37 | 2026-04-16-22-15-38-247 | 0805_H150 |  | NOT SPECIFIED |  |  |  | Working | 23 | PTC_SYSTEM_MTRL_PROPS
20.1.38 | 2026-04-16-22-15-38-262 | 115-2544-000_1 |  | NOT SPECIFIED |  |  |  | Working | 3 | PTC_SYSTEM_MTRL_PROPS
20.1.39 | 2026-04-16-22-15-38-273 | 115-2947-000_1 |  | NOT SPECIFIED |  |  |  | Working | 1 | PTC_SYSTEM_MTRL_PROPS
20.1.40 | 2026-04-16-22-15-38-259 | 300-0810-000_1 |  | NOT SPECIFIED |  |  |  | Working | 1 | PTC_SYSTEM_MTRL_PROPS
20.1.41 | 2026-04-16-22-15-38-229 | 080-1749-000_1 |  | NOT SPECIFIED |  |  |  | Working | 1 | PTC_SYSTEM_MTRL_PROPS
20.1.42 | 2026-04-16-22-15-38-315 | 080-1927-000_1 |  | NOT SPECIFIED |  |  |  | Working | 1 | PTC_SYSTEM_MTRL_PROPS
20.1.43 | 2026-04-16-22-15-38-288 | 0603_H070 |  | NOT SPECIFIED |  |  |  | Working | 6 | PTC_SYSTEM_MTRL_PROPS
20.1.44 | 2026-04-16-22-15-38-218 | 115-0881-000_1 |  | NOT SPECIFIED |  |  |  | Working | 1 | PTC_SYSTEM_MTRL_PROPS
20.1.45 | 2026-04-16-22-15-38-214 | 064-0535-000_2 |  | NOT SPECIFIED |  |  |  | Working | 1 | PTC_SYSTEM_MTRL_PROPS
20.1.46 | 2026-04-16-22-15-38-316 | 080-1928-000_1 |  | NOT SPECIFIED |  |  |  | Working | 1 | PTC_SYSTEM_MTRL_PROPS
20.1.47 | 2026-04-16-22-15-38-239 | 115-2189-000_2 |  | NOT SPECIFIED |  |  |  | Working | 5 | PTC_SYSTEM_MTRL_PROPS
20.1.48 | 2026-04-16-22-15-38-209 | 315-1245-000_1 |  | NOT SPECIFIED |  |  |  | Working | 2 | PTC_SYSTEM_MTRL_PROPS
20.1.49 | 2026-04-16-22-15-38-297 | 085-0365-000_1 |  | NOT SPECIFIED |  |  |  | Working | 1 | PTC_SYSTEM_MTRL_PROPS
20.1.50 | 2026-04-16-22-15-38-306 | 300-1128-000_1 |  | NOT SPECIFIED |  |  |  | Working | 1 | AL6061
20.1.51 | 2026-04-16-22-15-38-269 | 080-1489-000_3 |  | NOT SPECIFIED |  |  |  | Working | 1 | PTC_SYSTEM_MTRL_PROPS
20.1.52 | 2026-04-16-22-15-38-292 | 115-1921-000_3 |  | NOT SPECIFIED |  |  |  | Working | 4 | AL6061
20.1.53 | 2026-04-16-22-15-38-233 | 080-1761-000_1 |  | NOT SPECIFIED |  |  |  | Working | 1 | PTC_SYSTEM_MTRL_PROPS
20.1.54 | 2026-04-16-22-15-38-300 | 086-0282-000_1 |  | NOT SPECIFIED |  |  |  | Working | 2 | PTC_SYSTEM_MTRL_PROPS
20.1.55 | 2026-04-16-22-15-38-150 | 600-13737-0000-A01 |  | NOT SPECIFIED |  |  |  | Working | 1 | Steel
20.1.56 | 2026-04-16-22-15-38-256 | 131-0134-000_4 |  | NOT SPECIFIED |  |  |  | Working | 1 | PTC_SYSTEM_MTRL_PROPS
20.1.57 | 2026-04-16-22-15-38-227 | 316-0703-000_1 |  | NOT SPECIFIED |  |  |  | Working | 3 | AL6061
20.1.58 | 2026-04-16-22-15-38-245 | 090-0134-000_2 |  | NOT SPECIFIED |  |  |  | Working | 13 | PTC_SYSTEM_MTRL_PROPS
20.1.59 | 2026-04-16-22-15-38-263 | 300-0662-000_1 |  | NOT SPECIFIED |  |  |  | Working | 8 | PTC_SYSTEM_MTRL_PROPS
20.1.60 | 2026-04-16-22-15-38-154 | 130-1575-000_1 |  | NOT SPECIFIED |  |  |  | Working | 1 | AL6061
20.1.61 | 2026-04-16-22-15-38-272 | 115-0085-000_1 |  | NOT SPECIFIED |  |  |  | Working | 1 | PTC_SYSTEM_MTRL_PROPS
20.1.62 | 2026-04-16-22-15-38-224 | 091-0080-000_1 |  | NOT SPECIFIED |  |  |  | Working | 1 | PTC_SYSTEM_MTRL_PROPS
20.1.63 | 2026-04-16-22-15-38-320 | VST_071C125D |  | NOT SPECIFIED |  |  |  | Working | 13 | PTC_SYSTEM_MTRL_PROPS
20.1.64 | 2026-04-16-22-15-38-312 | SO08_048X038 |  | NOT SPECIFIED |  |  |  | Working | 1 | PTC_SYSTEM_MTRL_PROPS
20.1.65 | 2026-04-16-22-15-38-246 | 0805_H160 |  | NOT SPECIFIED |  |  |  | Working | 20 | PTC_SYSTEM_MTRL_PROPS
20.1.66 | 2026-04-16-22-15-38-277 | 115-2514-000_1 |  | NOT SPECIFIED |  |  |  | Working | 1 | PTC_SYSTEM_MTRL_PROPS
20.1.67 | 2026-04-16-22-15-38-244 | 316-0314-000_1 |  | NOT SPECIFIED |  |  |  | Working | 2 | PTC_SYSTEM_MTRL_PROPS
20.1.68 | 2026-04-16-22-15-38-299 | 130-1221-000_1 |  | NOT SPECIFIED |  |  |  | Working | 3 | PTC_SYSTEM_MTRL_PROPS
20.1.69 | 2026-04-16-22-15-38-309 | 080-1923-000_1 |  | NOT SPECIFIED |  |  |  | Working | 1 | PTC_SYSTEM_MTRL_PROPS
20.1.70 | 2026-04-16-22-15-38-279 | 300-0381-000_1 |  | NOT SPECIFIED |  |  |  | Working | 3 | PTC_SYSTEM_MTRL_PROPS
20.1.71 | 2026-04-16-22-15-38-302 | 280-0161-000_1 |  | NOT SPECIFIED |  |  |  | Working | 3 | PTC_SYSTEM_MTRL_PROPS
20.1.72 | 2026-04-16-22-15-38-237 | 115-2766-000_1 |  | NOT SPECIFIED |  |  |  | Working | 2 | PTC_SYSTEM_MTRL_PROPS
20.1.73 | 2026-04-16-22-15-38-305 | 300-0817-000_2 |  | NOT SPECIFIED |  |  |  | Working | 6 | PTC_SYSTEM_MTRL_PROPS
20.1.74 | 2026-04-16-22-15-38-236 | LTPT071C125D |  | NOT SPECIFIED |  |  |  | Working | 124 | PTC_SYSTEM_MTRL_PROPS
20.1.75 | 2026-04-16-22-15-38-220 | 090-0378-000_1 |  | NOT SPECIFIED |  |  |  | Working | 3 | AL6061
20.1.76 | 2026-04-16-22-15-38-254 | 092-0241-000_1 |  | NOT SPECIFIED |  |  |  | Working | 1 | PTC_SYSTEM_MTRL_PROPS
20.1.77 | 2026-04-16-22-15-38-211 | 155-1175-000_1 |  | NOT SPECIFIED |  |  |  | Working | 3 | AL6061
20.1.78 | 2026-04-16-22-15-38-311 | 315-1257-000_1 |  | NOT SPECIFIED |  |  |  | Working | 1 | PTC_SYSTEM_MTRL_PROPS
20.1.79 | 2026-04-16-22-15-38-232 | 1206_H180 |  | NOT SPECIFIED |  |  |  | Working | 7 | PTC_SYSTEM_MTRL_PROPS
20.1.80 | 2026-04-16-22-15-38-235 | 090-0367-000_1 |  | NOT SPECIFIED |  |  |  | Working | 5 | PTC_SYSTEM_MTRL_PROPS
20.1.81 | 2026-04-16-22-15-38-310 | 080-1898-000_1 |  | NOT SPECIFIED |  |  |  | Working | 1 | PTC_SYSTEM_MTRL_PROPS
20.1.82 | 2026-04-16-22-15-38-151 | 065-0738-000_1 |  | NOT SPECIFIED |  |  |  | Working | 2 | PTC_SYSTEM_MTRL_PROPS
20.1.83 | 2026-04-16-22-15-38-314 | 064-0531-000_1 |  | NOT SPECIFIED |  |  |  | Working | 1 | PTC_SYSTEM_MTRL_PROPS
20.1.84 | 2026-04-16-22-15-38-291 | 300-1074-000_1 |  | NOT SPECIFIED |  |  |  | Working | 2 | PTC_SYSTEM_MTRL_PROPS
20.1.85 | 2026-04-16-22-15-38-281 | 300-0485-000_2 |  | NOT SPECIFIED |  |  |  | Working | 17 | PTC_SYSTEM_MTRL_PROPS
20.1.86 | 2026-04-16-22-15-38-298 | 115-2752-000_1 |  | NOT SPECIFIED |  |  |  | Working | 1 | AL6061
20.1.87 | 2026-04-16-22-15-38-230 | IND_SMD_0805_H110 |  | NOT SPECIFIED |  |  |  | Working | 2 | PTC_SYSTEM_MTRL_PROPS
20.1.88 | 2026-04-16-22-15-38-253 | LOGO_SILK_WEEE_0485X0683 |  | NOT SPECIFIED |  |  |  | Working | 1 | PTC_SYSTEM_MTRL_PROPS
20.1.89 | 2026-04-16-22-15-38-295 | 115-2838-000_1 |  | NOT SPECIFIED |  |  |  | Working | 1 | PTC_SYSTEM_MTRL_PROPS
20.1.90 | 2026-04-16-22-15-38-270 | 080-1346-000_3 |  | NOT SPECIFIED |  |  |  | Working | 1 | AL6061
20.1.91 | 2026-04-16-22-15-38-155 | 130-0748-000_1 |  | NOT SPECIFIED |  |  |  | Working | 1 | PTC_SYSTEM_MTRL_PROPS
20.1.92 | 2026-04-16-22-15-38-308 | LOGO_SILK_NVIDIA_I0600X0330 |  | NOT SPECIFIED |  |  |  | Working | 1 | PTC_SYSTEM_MTRL_PROPS
20.1.93 | 2026-04-16-22-15-38-223 | 115-2054-000_1 |  | NOT SPECIFIED |  |  |  | Working | 1 | PTC_SYSTEM_MTRL_PROPS
20.1.94 | 2026-04-16-22-15-38-215 | 215-0379-000_1 |  | NOT SPECIFIED |  |  |  | Working | 2 | AL6061
20.1.95 | 2026-04-16-22-15-38-267 | 115-2146-000_1 |  | NOT SPECIFIED |  |  |  | Working | 1 | PTC_SYSTEM_MTRL_PROPS
20.1.96 | 2026-04-16-22-15-38-318 | LOGO_SILK_180_I560 |  | NOT SPECIFIED |  |  |  | Working | 1 | PTC_SYSTEM_MTRL_PROPS
20.1.97 | 2026-04-16-22-15-38-290 | 300-0992-000_2 |  | NOT SPECIFIED |  |  |  | Working | 2 | AL6061
20.1.98 | 2026-04-16-22-15-38-265 | 115-1680-000_1 |  | NOT SPECIFIED |  |  |  | Working | 4 | PTC_SYSTEM_MTRL_PROPS
20.1.99 | 2026-04-16-22-15-38-268 | 315-1235-000_1 |  | NOT SPECIFIED |  |  |  | Working | 1 | PTC_SYSTEM_MTRL_PROPS
20.1.100 | 2026-04-16-22-15-38-317 | 080-1926-000_3 |  | NOT SPECIFIED |  |  |  | Working | 1 | PTC_SYSTEM_MTRL_PROPS
20.1.101 | 2026-04-16-22-15-38-274 | 115-1426-000_1 |  | NOT SPECIFIED |  |  |  | Working | 3 | PTC_SYSTEM_MTRL_PROPS
20.1.102 | 2026-04-16-22-15-38-276 | 115-1821-000_1 |  | NOT SPECIFIED |  |  |  | Working | 5 | PTC_SYSTEM_MTRL_PROPS
20.1.103 | 2026-04-16-22-15-38-278 | 115-0138-000_1 |  | NOT SPECIFIED |  |  |  | Working | 1 | PTC_SYSTEM_MTRL_PROPS
20.1.104 | 2026-04-16-22-15-38-250 | 0805_H060 |  | NOT SPECIFIED |  |  |  | Working | 6 | PTC_SYSTEM_MTRL_PROPS
20.1.105 | 2026-04-16-22-15-38-226 | 316-0613-000_2 |  | NOT SPECIFIED |  |  |  | Working | 2 | PTC_SYSTEM_MTRL_PROPS
20.1.106 | 2026-04-16-22-15-38-217 | 315-1258-000_1 |  | NOT SPECIFIED |  |  |  | Working | 1 | PTC_SYSTEM_MTRL_PROPS
20.1.107 | 2026-04-16-22-15-38-313 | 086-0303-000_1 |  | NOT SPECIFIED |  |  |  | Working | 1 | PTC_SYSTEM_MTRL_PROPS
20.1.108 | 2026-04-16-22-15-38-293 | 130-0846-000_1 |  | NOT SPECIFIED |  |  |  | Working | 1 | PTC_SYSTEM_MTRL_PROPS
20.1.109 | 2026-04-16-22-15-38-248 | 0805_H070 |  | NOT SPECIFIED |  |  |  | Working | 2 | PTC_SYSTEM_MTRL_PROPS
20.1.110 | 2026-04-16-22-15-38-242 | CON_HDR_002X005_SMD_ST_M_P_GREY |  | NOT SPECIFIED |  |  |  | Working | 1 | Steel
20.1.111 | 2026-04-16-22-15-38-243 | LOGO_SILK_ROHS_D050_CHINA |  | NOT SPECIFIED |  |  |  | Working | 1 | PTC_SYSTEM_MTRL_PROPS
20.1.112 | 2026-04-16-22-15-38-255 | LOGO_SILK_HF_I0185X0120 |  | NOT SPECIFIED |  |  |  | Working | 1 | PTC_SYSTEM_MTRL_PROPS
20.1.113 | 2026-04-16-22-15-38-294 | MEC_STANDOFF_PTH_620C380P |  | NOT SPECIFIED |  |  |  | Working | 1 | PTC_SYSTEM_MTRL_PROPS
20.1.114 | 2026-04-16-22-15-38-212 | 320-0965-000_5 |  | NOT SPECIFIED |  |  |  | Working | 1 | AL6061
20.1.115 | 2026-04-16-22-15-38-251 | 032-0796-000_1 |  | NOT SPECIFIED |  |  |  | Working | 3 | PTC_SYSTEM_MTRL_PROPS
20.1.116 | 2026-04-16-22-15-38-301 | 085-0347-000_1 |  | NOT SPECIFIED |  |  |  | Working | 1 | PTC_SYSTEM_MTRL_PROPS
20.1.117 | 2026-04-16-22-15-38-228 | 315-1041-000_3 |  | NOT SPECIFIED |  |  |  | Working | 2 | AL6061
20.1.118 | 2026-04-16-22-15-38-286 | 0402_H070 |  | NOT SPECIFIED |  |  |  | Working | 3 | PTC_SYSTEM_MTRL_PROPS
20.1.119 | 2026-04-16-22-15-38-303 | QFN040Q_P050_0065_T047X047 |  | NOT SPECIFIED |  |  |  | Working | 1 | PTC_SYSTEM_MTRL_PROPS
20.1.120 | 2026-04-16-22-15-38-153 | LL_VENDOR_DATECODE_TOP_2R |  | NOT SPECIFIED |  |  |  | Working | 1 | PTC_SYSTEM_MTRL_PROPS
20.2 | 2026-04-16-22-15-38-402 | PCIE_COVER_CONCORD_ASM |  | NOT SPECIFIED |  |  |  | Working | 1
20.2.1 | 2026-04-16-22-15-38-406 | MAGNET_PCIE_CVR_CONCORD_ASSY_ASM |  | NOT SPECIFIED |  |  |  | Working | 3
20.2.1.1 | 2026-04-16-22-15-38-407 | MAGNET_PCIE_CVR_CONCORD |  | NOT SPECIFIED |  |  |  | Working | 1 | PTC_SYSTEM_MTRL_PROPS
20.2.2 | 2026-04-16-22-15-38-410 | 371-0232-000 |  | NOT SPECIFIED |  |  |  | Working | 1 | PTC_SYSTEM_MTRL_PROPS
20.2.3 | 2026-04-16-22-15-38-409 | MYLAR_MAGNET_PCIE_CVR_2 |  | NOT SPECIFIED |  |  |  | Working | 1 | PTC_SYSTEM_MTRL_PROPS
20.2.4 | 2026-04-16-22-15-38-404 | ANT-ASSEMBLY_FR4-1 |  | NOT SPECIFIED |  |  |  | Working | 1 | Steel
20.2.5 | 2026-04-16-22-15-38-408 | MYLAR_MAGNET_PCIE_CVR |  | NOT SPECIFIED |  |  |  | Working | 1 | PTC_SYSTEM_MTRL_PROPS
20.2.6 | 2026-04-16-22-15-38-405 | ANT-ASSEMBLY_FR4-2 |  | NOT SPECIFIED |  |  |  | Working | 1 | Steel
20.2.7 | 2026-04-16-22-15-38-403 | PCIE_COVER_CONCORD |  | NOT SPECIFIED |  |  |  | Working | 1 | PTC_SYSTEM_MTRL_PROPS
20.3 | 2026-04-16-22-15-38-411 | SCREW_M2_5_25_3 |  | NOT SPECIFIED |  |  |  | Working | 4 | Steel
20.4 | 2026-04-16-22-15-38-376 | 245-13701-0000-000_ASM |  | NOT SPECIFIED |  |  |  | Working | 1
20.4.1 | 2026-04-16-22-15-38-377 | 600-13701-BASE-A00_ASM |  | NOT SPECIFIED |  |  |  | Working | 1
20.4.1.1 | 2026-04-16-22-15-38-378 | 080-1502-000_4 |  | NOT SPECIFIED |  |  |  | Working | 1 | PTC_SYSTEM_MTRL_PROPS
20.4.2 | 2026-04-16-22-15-38-389 | 155-1167-000 |  | NOT SPECIFIED |  |  |  | Working | 4 | PTC_SYSTEM_MTRL_PROPS
20.4.3 | 2026-04-16-22-15-38-379 | 600-63701-BASE-A05_ASM |  | NOT SPECIFIED |  |  |  | Working | 1
20.4.3.1 | 2026-04-16-22-15-38-380 | 600-63701-BASE-A05 |  | NOT SPECIFIED |  |  |  | Working | 1 | Steel
20.4.4 | 2026-04-16-22-15-38-386 | HEATPIPE-P3701-LIDLESS |  | NOT SPECIFIED |  |  |  | Working | 2 | CU
20.4.5 | 2026-04-16-22-15-38-388 | 155-0532-000 |  | NOT SPECIFIED |  |  |  | Working | 4 | PTC_SYSTEM_MTRL_PROPS
20.4.6 | 2026-04-16-22-15-38-381 | 320-1885-000-LIDLESS_ASM |  | NOT SPECIFIED |  |  |  | Working | 1
20.4.6.1 | 2026-04-16-22-15-38-382 | 320-1885-000 |  | NOT SPECIFIED |  |  |  | Working | 1 | AL6061
20.4.6.2 | 2026-04-16-22-15-38-384 | TTP-EAST-MEM |  | NOT SPECIFIED |  |  |  | Working | 1 | CU
20.4.6.3 | 2026-04-16-22-15-38-385 | TTP-SOUTH-MEM-2 |  | NOT SPECIFIED |  |  |  | Working | 1 | CU
20.4.6.4 | 2026-04-16-22-15-38-383 | SPREADER-P3701-LIDLESS |  | NOT SPECIFIED |  |  |  | Working | 1 | CU
20.4.7 | 2026-04-16-22-15-38-387 | 367-0600-000A |  | NOT SPECIFIED |  |  |  | Working | 1 | PTC_SYSTEM_MTRL_PROPS
20.5 | 2026-04-16-22-15-38-400 | 330-0266-000_M2_WIFI_MODULE_ASM |  | NOT SPECIFIED |  |  |  | Working | 1
20.5.1 | 2026-04-16-22-15-38-401 | 330-0266-000_MODULE_BOARD |  | NOT SPECIFIED |  |  |  | Working | 1 | PTC_SYSTEM_MTRL_PROPS
20.6 | 2026-04-16-22-15-38-367 | FOOT_CONCCORD_ASM |  | NOT SPECIFIED |  |  |  | Working | 1
20.6.1 | 2026-04-16-22-15-38-371 | FOOT_RUBBER_CONCORD_2 |  | NOT SPECIFIED |  |  |  | Working | 1 | PTC_SYSTEM_MTRL_PROPS
20.6.2 | 2026-04-16-22-15-38-369 | FOOT_CONCORD_BUTTON_RUBBER |  | NOT SPECIFIED |  |  |  | Working | 1 | PTC_SYSTEM_MTRL_PROPS
20.6.3 | 2026-04-16-22-15-38-372 | LG-4_CONCORD_0420 |  | NOT SPECIFIED |  |  |  | Working | 1 | Steel
20.6.4 | 2026-04-16-22-15-38-373 | ADHESIVE_FOOT_COVER_CONCORD |  | NOT SPECIFIED |  |  |  | Working | 1 | PTC_SYSTEM_MTRL_PROPS
20.6.5 | 2026-04-16-22-15-38-374 | ADHESIVE_FEET_CONCORD |  | NOT SPECIFIED |  |  |  | Working | 1 | PTC_SYSTEM_MTRL_PROPS
20.6.6 | 2026-04-16-22-15-38-368 | FOOT_CONCORD |  | NOT SPECIFIED |  |  |  | Working | 1 | PTC_SYSTEM_MTRL_PROPS
20.6.7 | 2026-04-16-22-15-38-375 | ADHESIVE_FEET_CONCORD_2 |  | NOT SPECIFIED |  |  |  | Working | 1 | PTC_SYSTEM_MTRL_PROPS
20.6.8 | 2026-04-16-22-15-38-370 | FOOT_RUBBER_CONCORD |  | NOT SPECIFIED |  |  |  | Working | 1 | PTC_SYSTEM_MTRL_PROPS
20.7 | 2026-04-16-22-15-38-390 | FANSINK_CONCORD_ASM |  | NOT SPECIFIED |  |  |  | Working | 1
20.7.1 | 2026-04-16-22-15-38-391 | FAN_COVER_CONCORD_COLLAPSIBLE |  | NOT SPECIFIED |  |  |  | Working | 1 | PTC_SYSTEM_MTRL_PROPS
20.7.2 | 2026-04-16-22-15-38-397 | GALEN_FAN_WIRE_SCREW |  | NOT SPECIFIED |  |  |  | Working | 1 | PTC_SYSTEM_MTRL_PROPS
20.7.3 | 2026-04-16-22-15-38-399 | CONCORD_FAN_SCREW |  | NOT SPECIFIED |  |  |  | Working | 3 | PTC_SYSTEM_MTRL_PROPS
20.7.4 | 2026-04-16-22-15-38-392 | HEATSINK_CONCORD |  | NOT SPECIFIED |  |  |  | Working | 1 | PTC_SYSTEM_MTRL_PROPS
20.7.5 | 2026-04-16-22-15-38-393 | CONCORD_FAN_ASSY_ASM |  | NOT SPECIFIED |  |  |  | Working | 1
20.7.5.1 | 2026-04-16-22-15-38-394 | 7014_ASSY_ASM_CONCORD_ASM |  | NOT SPECIFIED |  |  |  | Working | 1
20.7.5.1.1 | 2026-04-16-22-15-38-396 | 7014_IMPELLER_CONCORD |  | NOT SPECIFIED |  |  |  | Working | 1 | Steel
20.7.5.1.2 | 2026-04-16-22-15-38-395 | 7013_PILLOW_CONCORD |  | NOT SPECIFIED |  |  |  | Working | 1 | Steel
20.7.6 | 2026-04-16-22-15-38-398 | MAGNET_FAN_CVR_CONCORD |  | NOT SPECIFIED |  |  |  | Working | 6 | PTC_SYSTEM_MTRL_PROPS
20.8 | 2026-05-03-00-33-30-181 | stlpik |  |  |  |  |  | Working | 4 | Steel
20.9 | DIN 938 - M3 x 30 Steel 4.6 Plain | Stud DIN 938 - M3 x 30 Steel 4.6 Plain |  | Stud DIN 938 - M3 x 30 |  |  |  | Working | 4 | Steel 4.6, Plain
20.10 | DIN EN 24032 - M3 Steel 6 Plain | Hexagon Regular Nut DIN EN 24032 - M3 Steel 6 Plain |  | Hexagon Regular Nut DIN EN 24032 - M3 |  |  |  | Working | 4 | Steel 6, Plain
21 | 2026-05-02-12-46-54-079 | kamienok_profil |  |  |  |  |  | Working | 183 | Steel
22 | FCS JIS B 1111 (H) - M5x6 Steel 4.6 Plain | Countersunk Screw JIS B 1111 - M5x6 - H Steel 4.6 Plain |  | Countersunk Screw JIS B 1111 - M5x6 - H |  |  |  | Working | 120 | Steel 4.6, Plain
23 | DIN 912 - M5 x 0.8 x 6 Steel 4.6 Plain | Hexagon Socket Head Cap Screw DIN 912 - M5 x 0.8 x 6 Steel 4.6 Plain |  | Hexagon Socket Head Cap Screw DIN 912 - M5 x 0.8 x 6 |  |  |  | Working | 58 | Steel 4.6, Plain
24 | 2026-05-02-16-00-16-861 | pcb_with_IMU |  |  |  |  |  | Working | 13
24.1 | 2026-05-02-16-00-16-862 | PCB Component |  |  |  |  |  | Working | 1
24.1.1 | 2026-05-02-16-00-16-867 | 3,2 |  |  |  |  |  | Working | 4 | Steel
24.1.2 | 2026-05-02-16-00-16-863 | Board |  |  |  |  |  | Working | 1 | Steel
24.1.3 | 2026-05-02-16-00-16-864 | 10X03MTA |  |  |  |  |  | Working | 2 | Steel
24.1.4 | 2026-05-02-16-00-16-868 | JST_B2B-XH-A |  |  |  |  |  | Working | 1 | Steel
24.1.5 | 2026-05-02-16-00-16-866 | 10X04MTA |  |  |  |  |  | Working | 1 | Steel
24.1.6 | 2026-05-02-16-00-16-870 | 1X01 |  |  |  |  |  | Working | 2 | Steel
24.1.7 | 2026-05-02-16-00-16-865 | BLUE_PILL |  |  |  |  |  | Working | 1 | Steel
24.1.8 | 2026-05-02-16-00-16-869 | 1X08 |  |  |  |  |  | Working | 2 | Steel
24.2 | 2026-03-16-16-32-24-828 | 6DOF_IMU_24_Click_v100 |  | Open CASCADE Model |  |  |  | Working | 1
24.2.1 | 2026-03-25-19-01-00-205 | Component37 |  |  |  |  |  | Working | 1 | Steel
25 | BSHCS ASME B18.3.1M - M2x0.4 x 35 Steel Grade 2 Plain | Broached Hexagon Socket Head Cap Screw ASME B18.3.1M - M2x0.4 x 35 Steel Grade 2 Plain |  | Broached Hexagon Socket Head Cap Screw ASME B18.3.1M - M2x0.4 x 35 |  |  |  | Working | 4 | Steel Grade 2, Plain
26 | DIN 433 - 2.2 Steel 100 HV Plain | Washer DIN 433-1 - 2.2 - A Steel 100 HV Plain |  | Washer DIN 433-1 - 2.2 - A |  |  |  | Working | 4 | Steel 100 HV, Plain
27 | 2026-05-03-00-33-30-181 | stlpik |  |  |  |  |  | Working | 12 | Steel
28 | BSHCS ASME B18.3.1M - M2.5x0.45 x 30 Steel Grade 2 Plain | Broached Hexagon Socket Head Cap Screw ASME B18.3.1M - M2.5x0.45 x 30 Steel Grade 2 Plain |  | Broached Hexagon Socket Head Cap Screw ASME B18.3.1M - M2.5x0.45 x 30 |  |  |  | Working | 44 | Steel Grade 2, Plain
29 | DIN 125 - A 2.2 Steel 100 HV Plain | Washer DIN 125-1 - 2.2 - A Steel 100 HV Plain |  | Washer DIN 125-1 - 2.2 - A |  |  |  | Working | 44 | Steel 100 HV, Plain
30 | 2026-05-03-14-55-16-839 | lidar_connection_box |  |  |  |  |  | Working | 6 | Steel

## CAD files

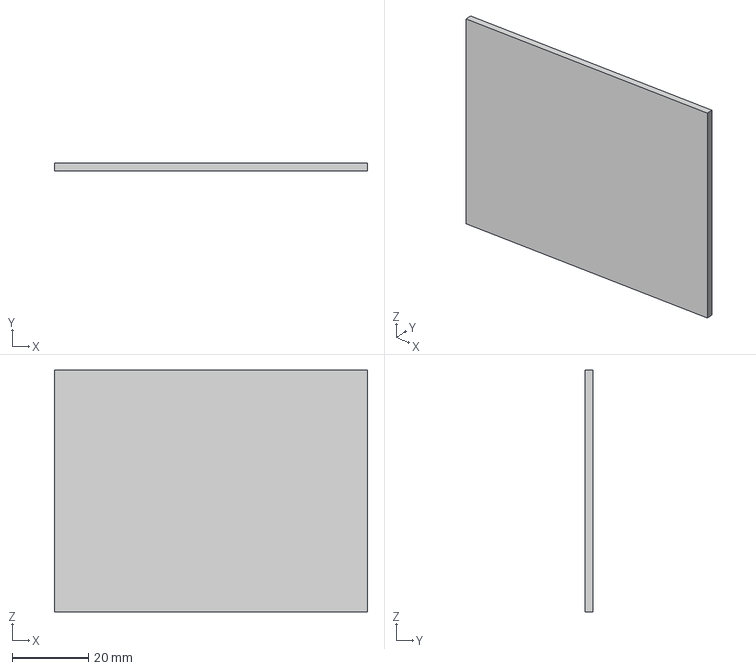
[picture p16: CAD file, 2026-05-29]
printable/step/sm_wall_back.step
82.3 x 2.00 x 63.6 mm

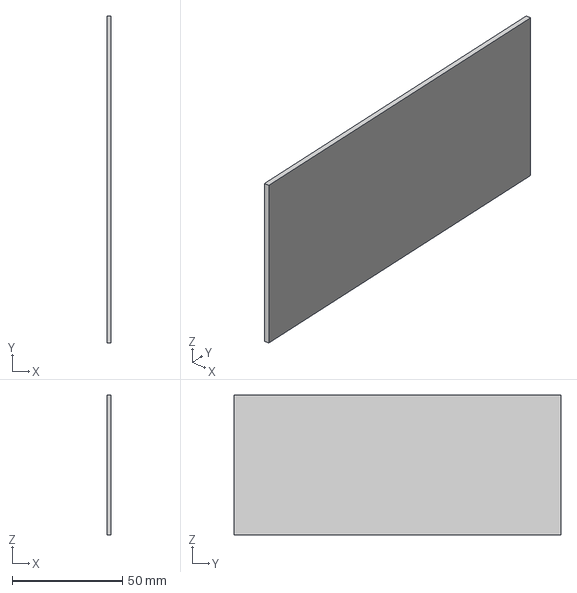
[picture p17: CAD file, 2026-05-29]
printable/step/sm_wall_side.step
2.00 x 148.6 x 63.6 mm

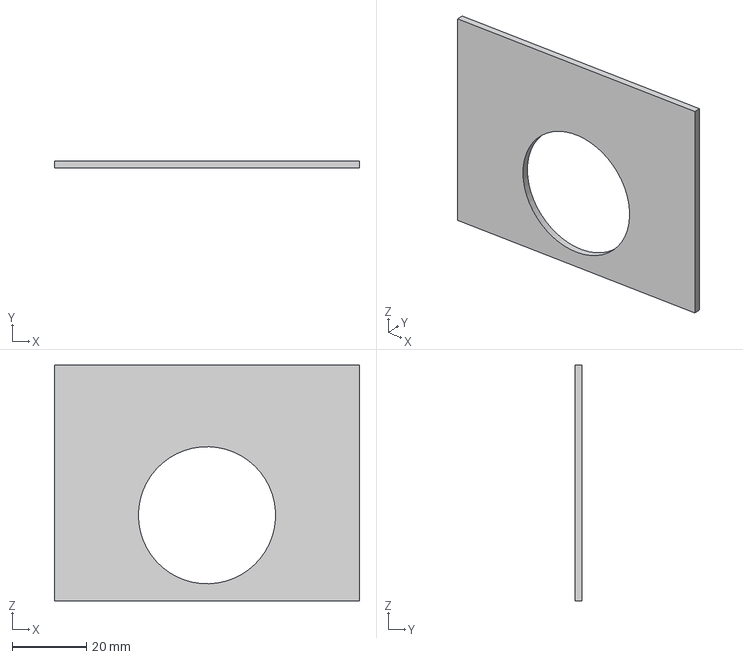
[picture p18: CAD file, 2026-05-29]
printable/step/sm_wall_front.step
82.3 x 2.00 x 63.6 mm

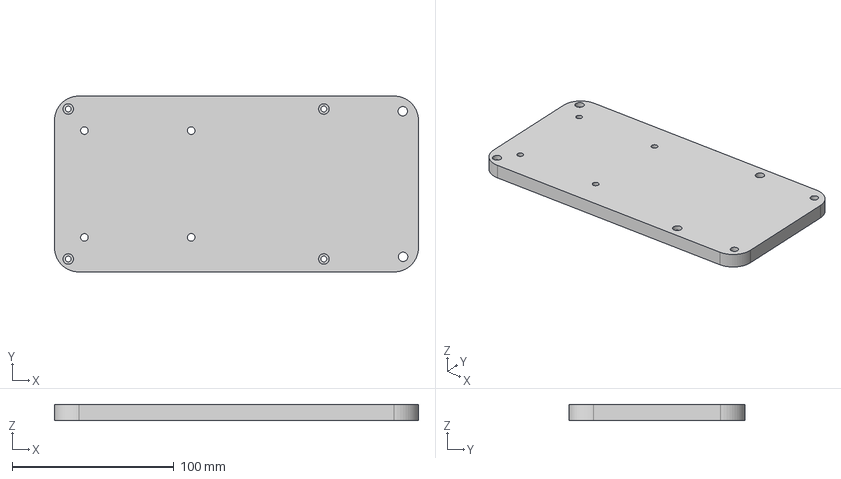
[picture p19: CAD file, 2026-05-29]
printable/step/sensors_modul_top.step
225.0 x 108.7 x 10.0 mm

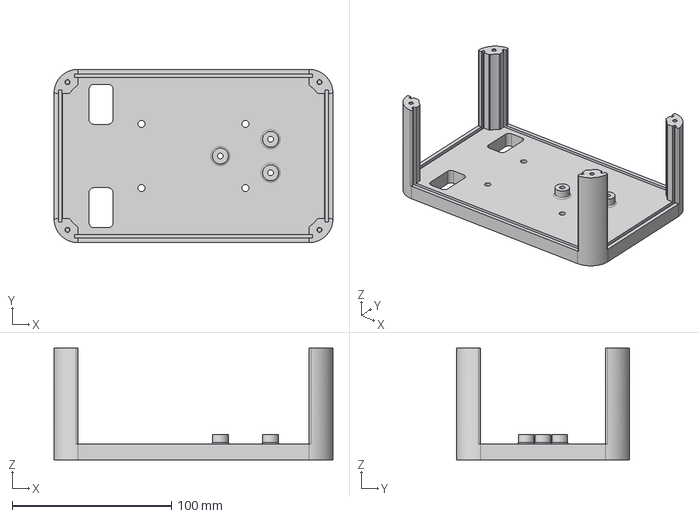
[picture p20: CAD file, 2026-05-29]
printable/step/sensors_module_bottom.step
175.0 x 108.7 x 70.0 mm

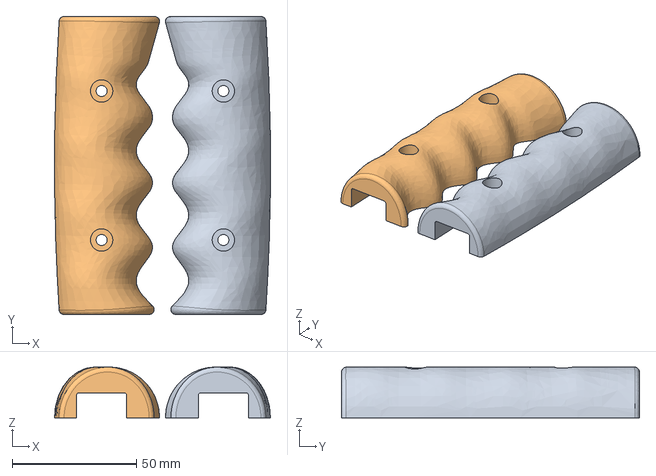
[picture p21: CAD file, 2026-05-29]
printable/step/handles.step
87.0 x 120.0 x 20.5 mm

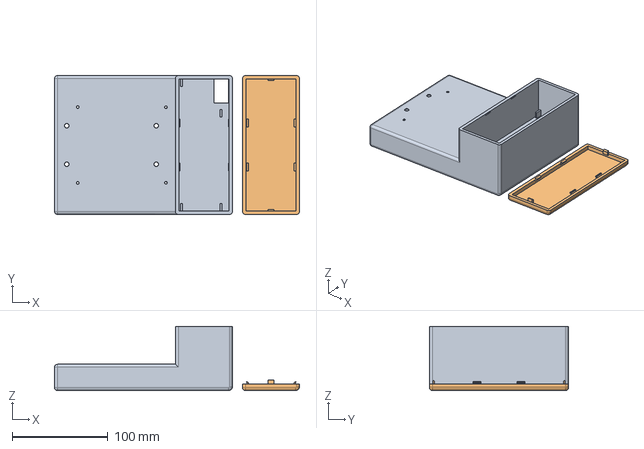
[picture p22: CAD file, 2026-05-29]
printable/step/acu_jetson_case.step
255.8 x 145.0 x 67.0 mm

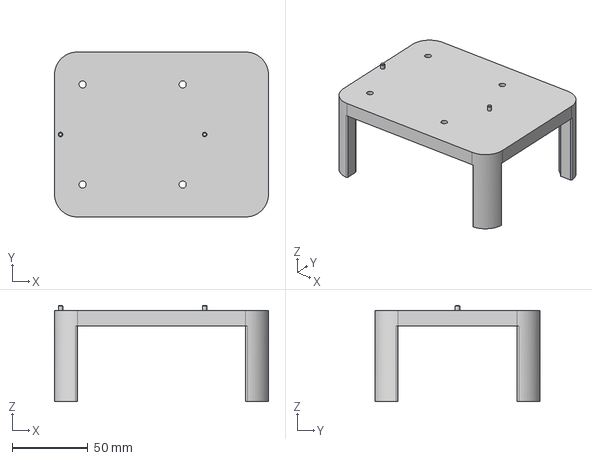
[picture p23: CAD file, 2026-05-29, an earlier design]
printable/step/old/sensors_modul_top.step
141.1 x 108.7 x 63.5 mm

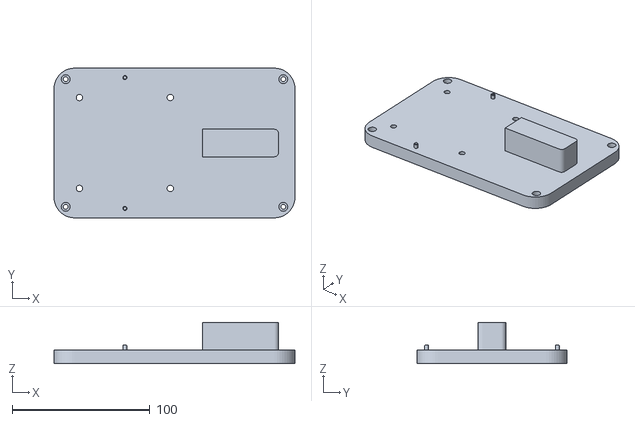
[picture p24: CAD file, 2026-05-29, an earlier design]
printable/stl/old/sensors_modul_top_v2.stl
175.0 x 108.7 x 30.0

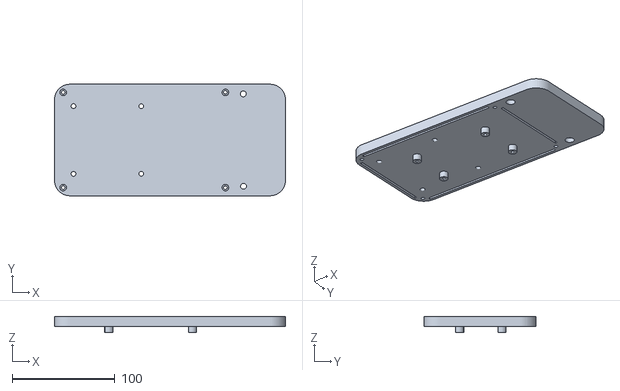
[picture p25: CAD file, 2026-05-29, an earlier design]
printable/stl/old2/sensors_modul_top_v3.stl
225.0 x 108.7 x 16.0

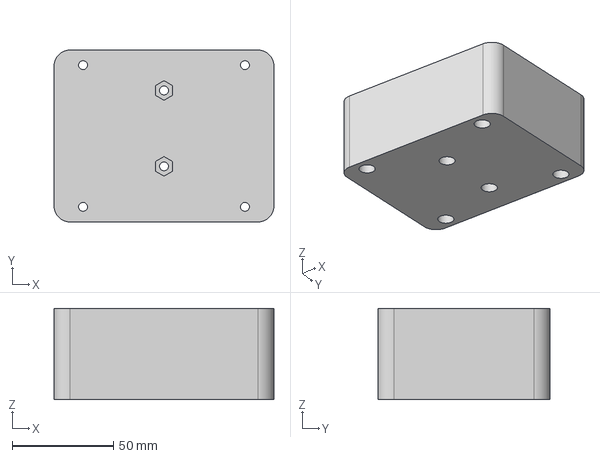
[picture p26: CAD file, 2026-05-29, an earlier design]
printable/step/old/sensors_module_platform.step
108.7 x 85.0 x 45.0 mm

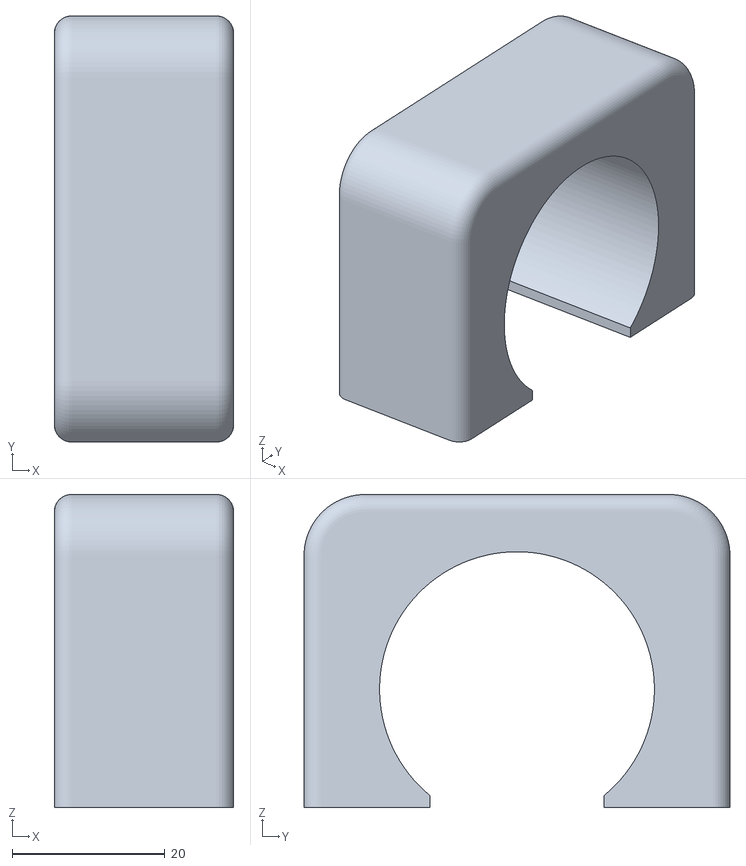
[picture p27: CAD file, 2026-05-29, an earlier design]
printable/stl/old2/lens_cover.stl
23.5 x 55.8 x 41.0

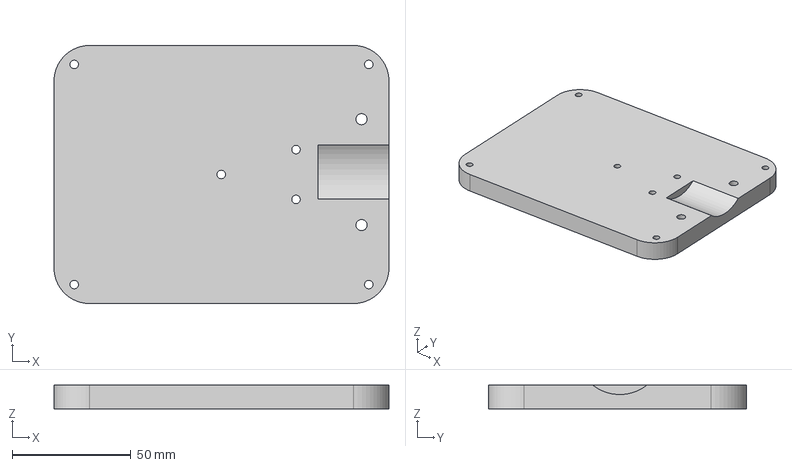
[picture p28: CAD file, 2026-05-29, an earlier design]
printable/step/old/sensors_module_bottom.step
141.1 x 108.7 x 10.0 mm

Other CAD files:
printable/stl/old2/sensors_module_platform.stl
printable/step/old/sensors_module_bottom_v2.step
printable/stl/old2/sm_wall_back.stl
printable/step/old/sensors_modul_top_v3.step
printable/stl/old2/sensors_module_bottom_v2.stl
printable/step/old/lens_cover.step
printable/stl/acu_jetson_case.stl
printable/stl/handles.stl
printable/stl/old2/handles1.stl
printable/stl/old2/podstavec.stl
printable/stl/old2/sm_wall_front.stl
printable/stl/sensors_modul_top.stl
printable/stl/sensors_module_bottom.stl
printable/stl/sm_wall_back.stl
printable/stl/sm_wall_front.stl
printable/stl/sm_wall_side.stl

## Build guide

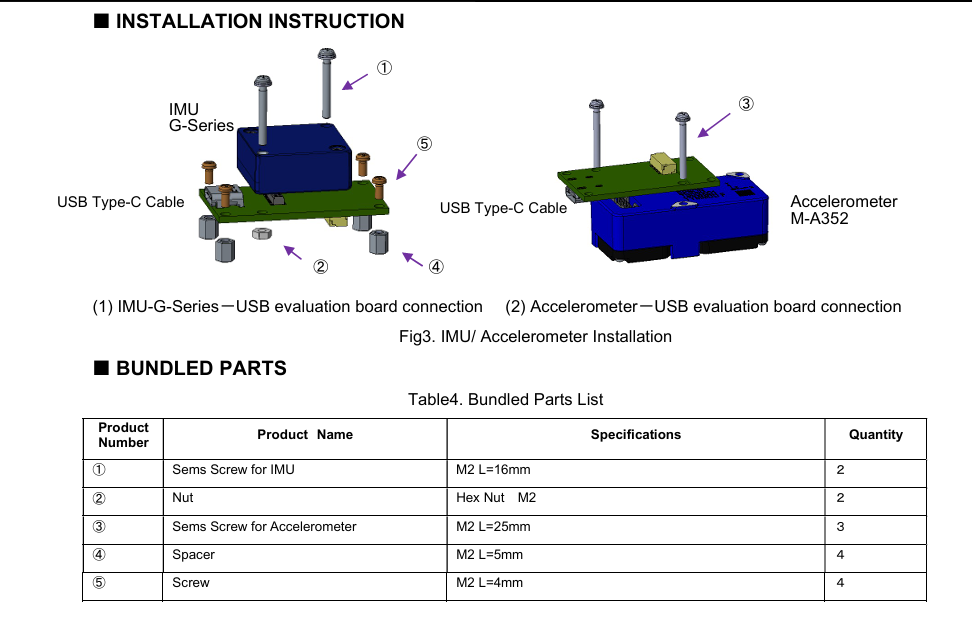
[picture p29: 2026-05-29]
parameters_datasheets/IMU_board_installation_instructions.png

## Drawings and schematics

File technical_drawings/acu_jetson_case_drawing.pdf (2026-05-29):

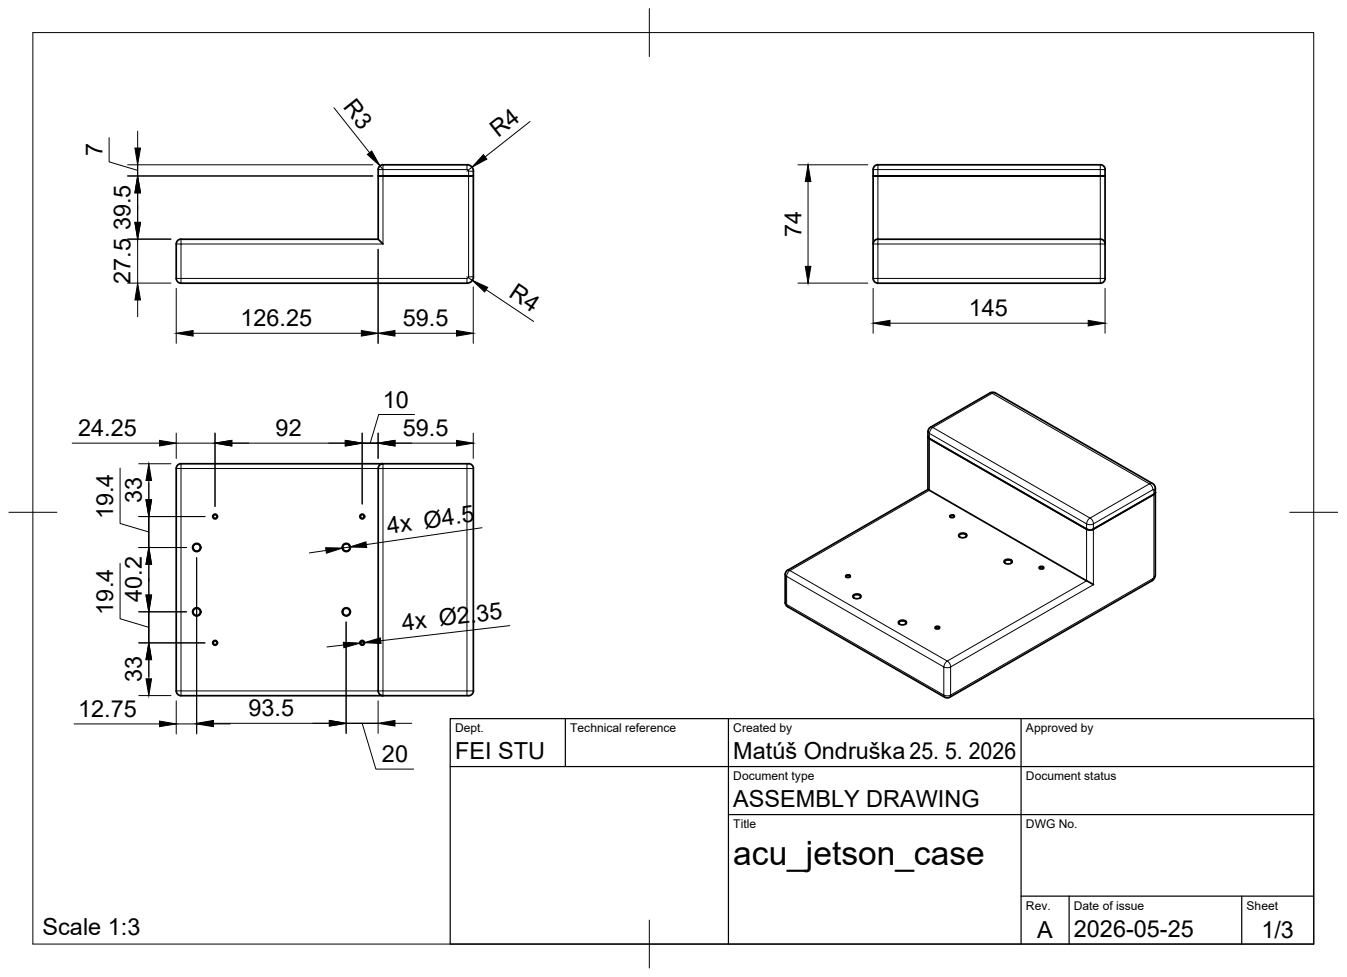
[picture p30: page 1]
FEI STU; Matúš Ondruška 27.5 39.5; Scale 1:3

Dept. | Technical reference | Created by 25. 5. 2026 | Approved by

Document type ASSEMBLY DRAWING | Document status

Title acu_jetson_case | DWG No.

Rev. A | Date of issue 2026-05-25 | Sheet

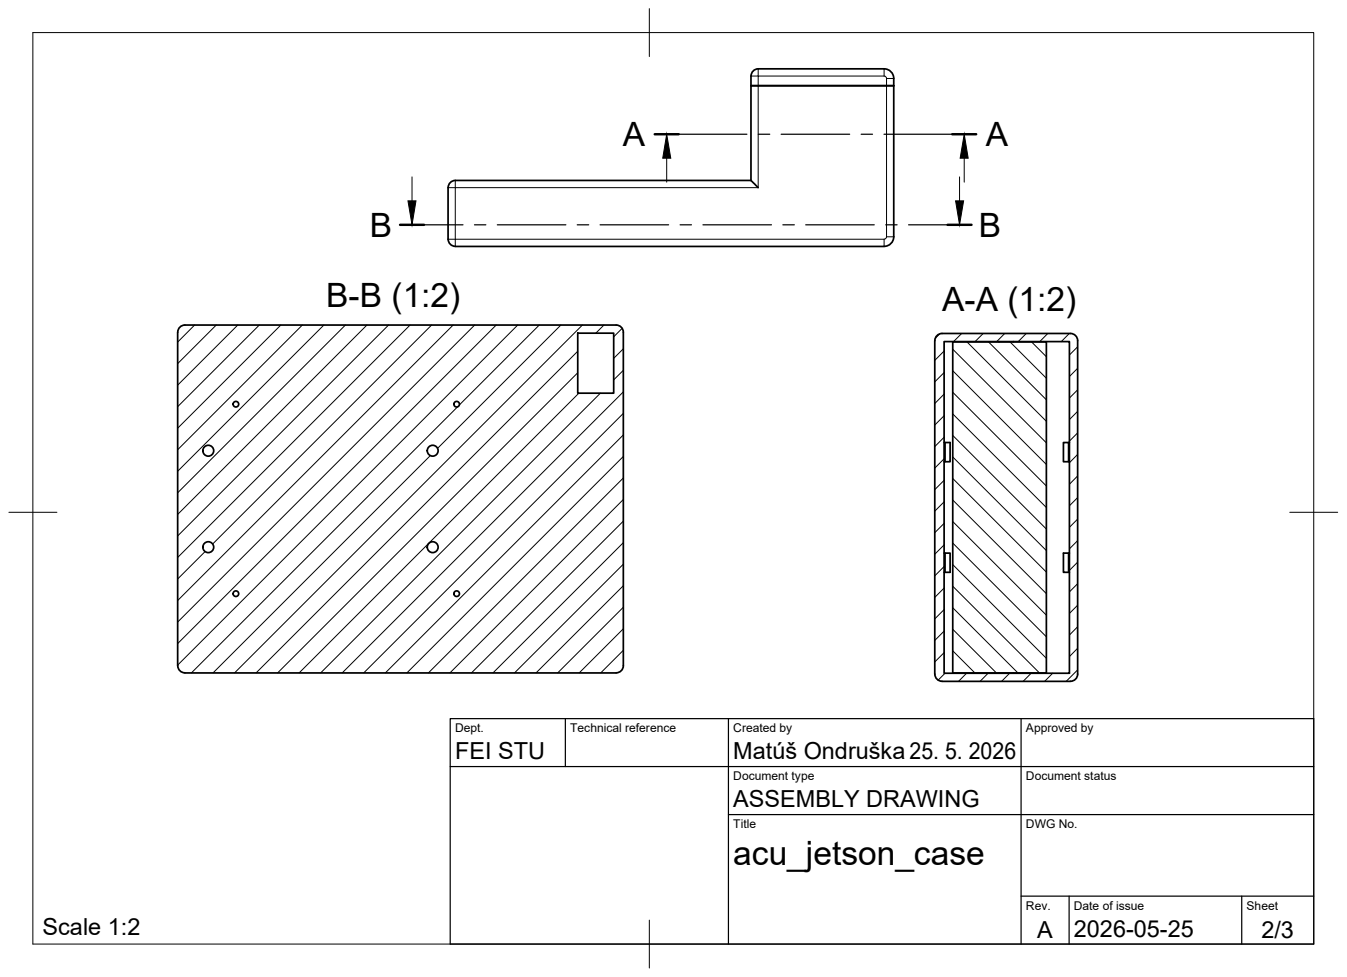
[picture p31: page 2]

Dept. FEI STU | Technical reference | Created by Matúš Ondruška 25. 5. 2026 | Approved by

Document type ASSEMBLY DRAWING | Document status

Title acu_jetson_case | DWG No.

Rev. | Date of issue | Sheet

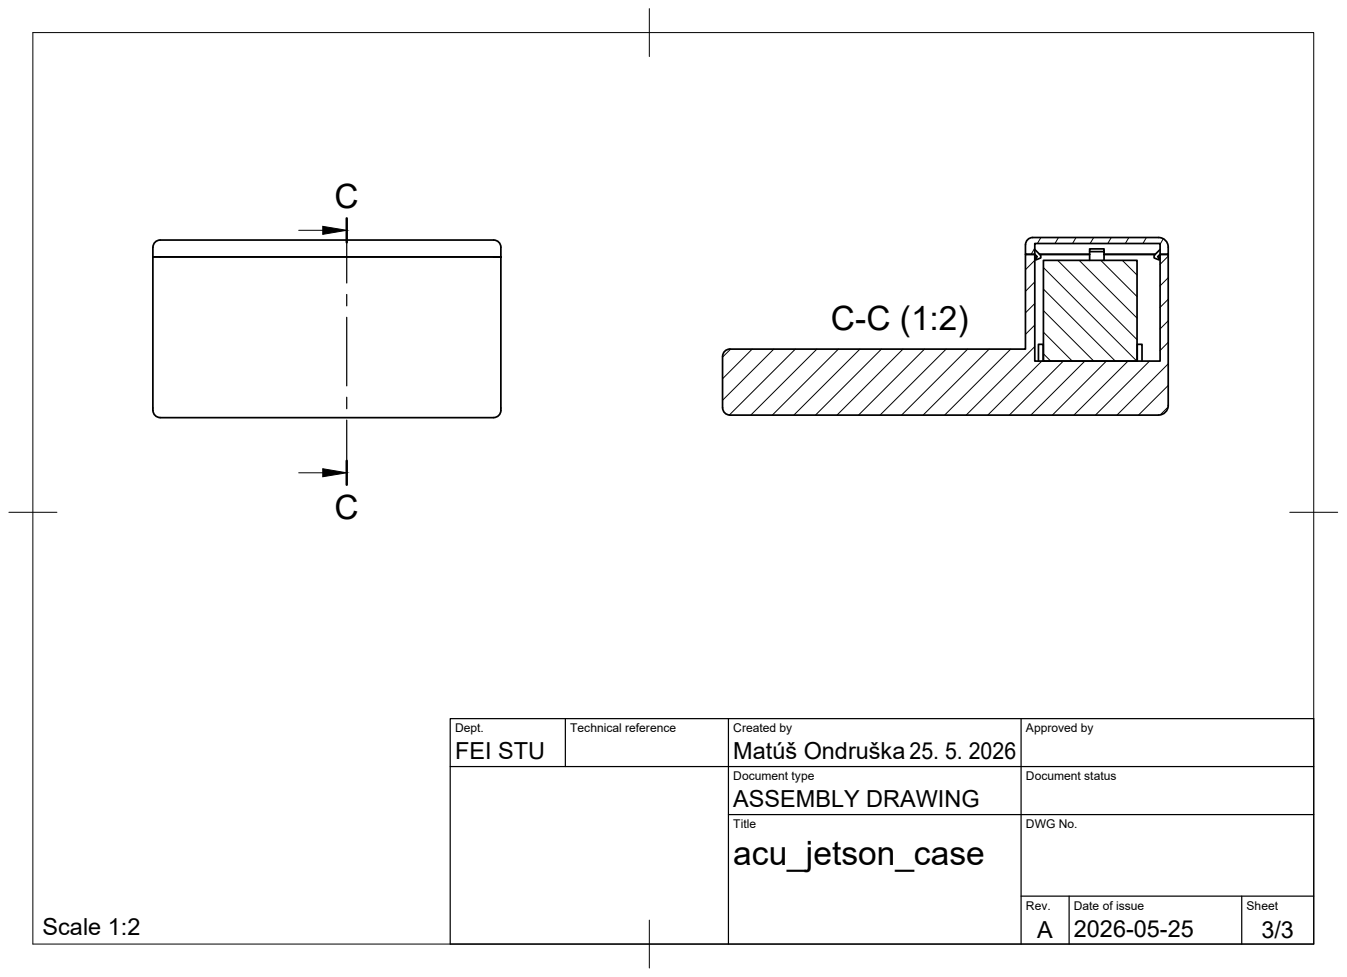
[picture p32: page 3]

Dept. FEI STU | Technical reference | Created by Matúš Ondruška 25. 5. 2026 | Approved by

Document type ASSEMBLY DRAWING | Document status

Title acu_jetson_case | DWG No.

Rev. | Date of issue | Sheet

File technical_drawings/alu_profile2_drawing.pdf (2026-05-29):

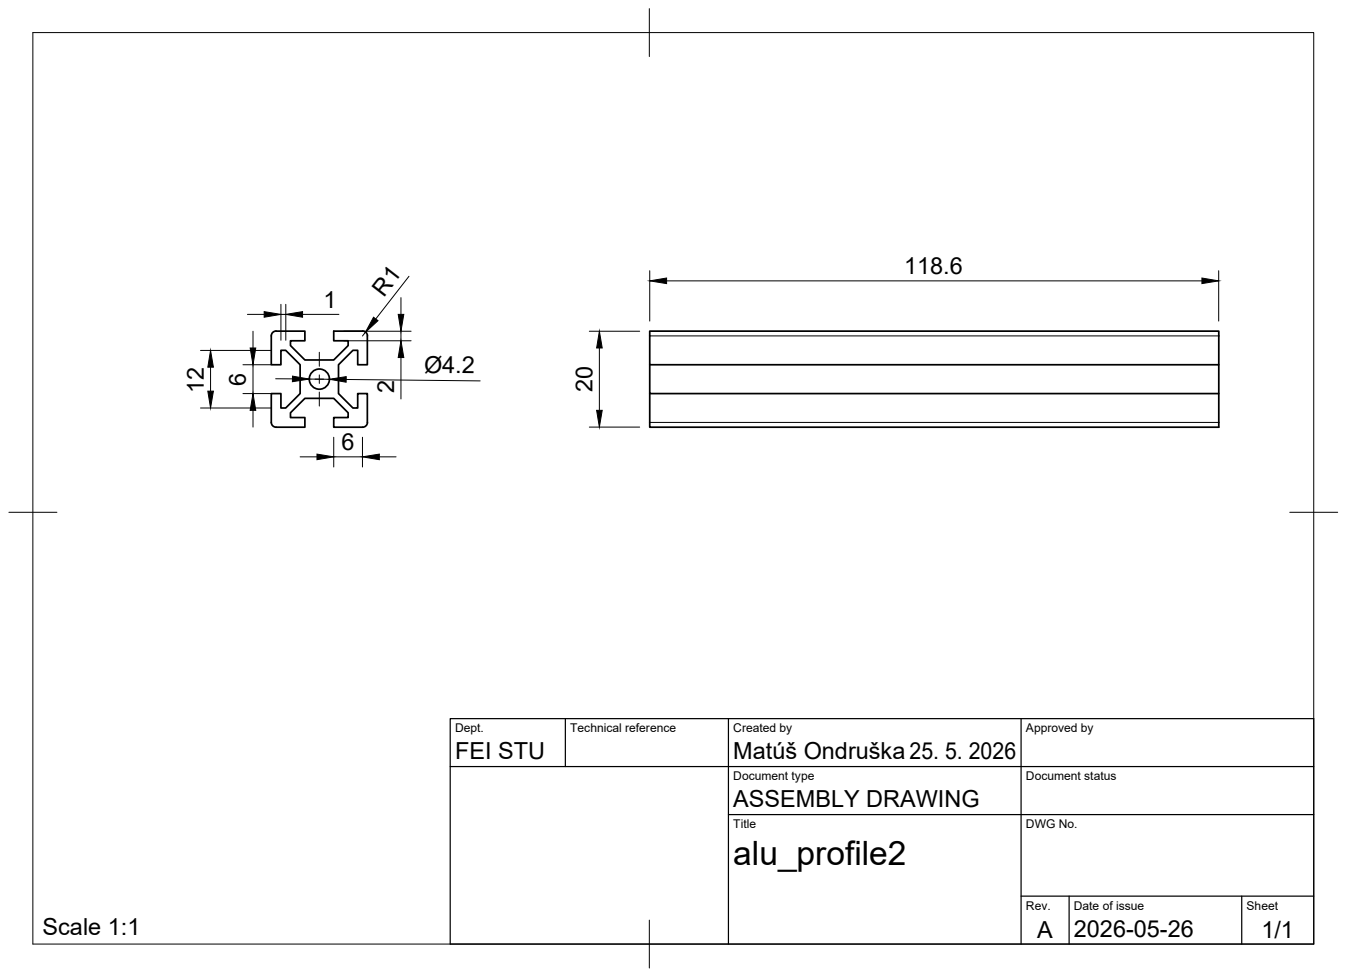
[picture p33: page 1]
Scale 1:1

Dept. FEI STU | Technical reference | Created by Matúš Ondruška 25. 5. 2026 | Approved by

Document type ASSEMBLY DRAWING | Document status

Title alu_profile2 | DWG No.

Rev. A | Date of issue 2026-05-26 | Sheet 1/1

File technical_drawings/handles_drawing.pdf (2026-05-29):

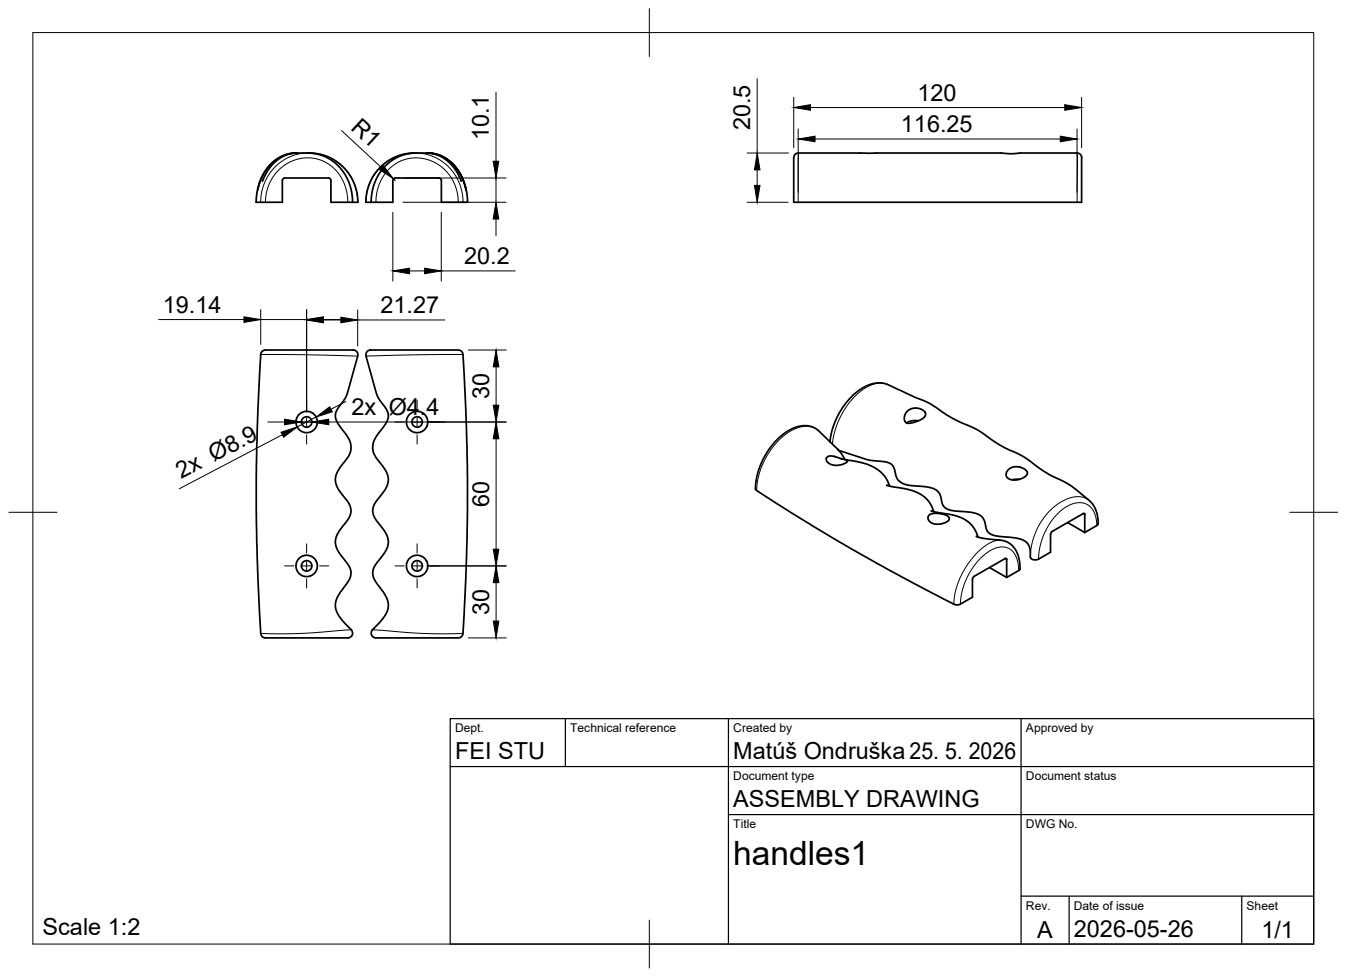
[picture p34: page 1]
Scale 1:2

Dept. FEI STU | Technical reference | Created by Matúš Ondruška 25. 5. 2026 | Approved by

Document type ASSEMBLY DRAWING | Document status

Title handles1 | DWG No.

Rev. A | Date of issue 2026-05-26 | Sheet 1/1

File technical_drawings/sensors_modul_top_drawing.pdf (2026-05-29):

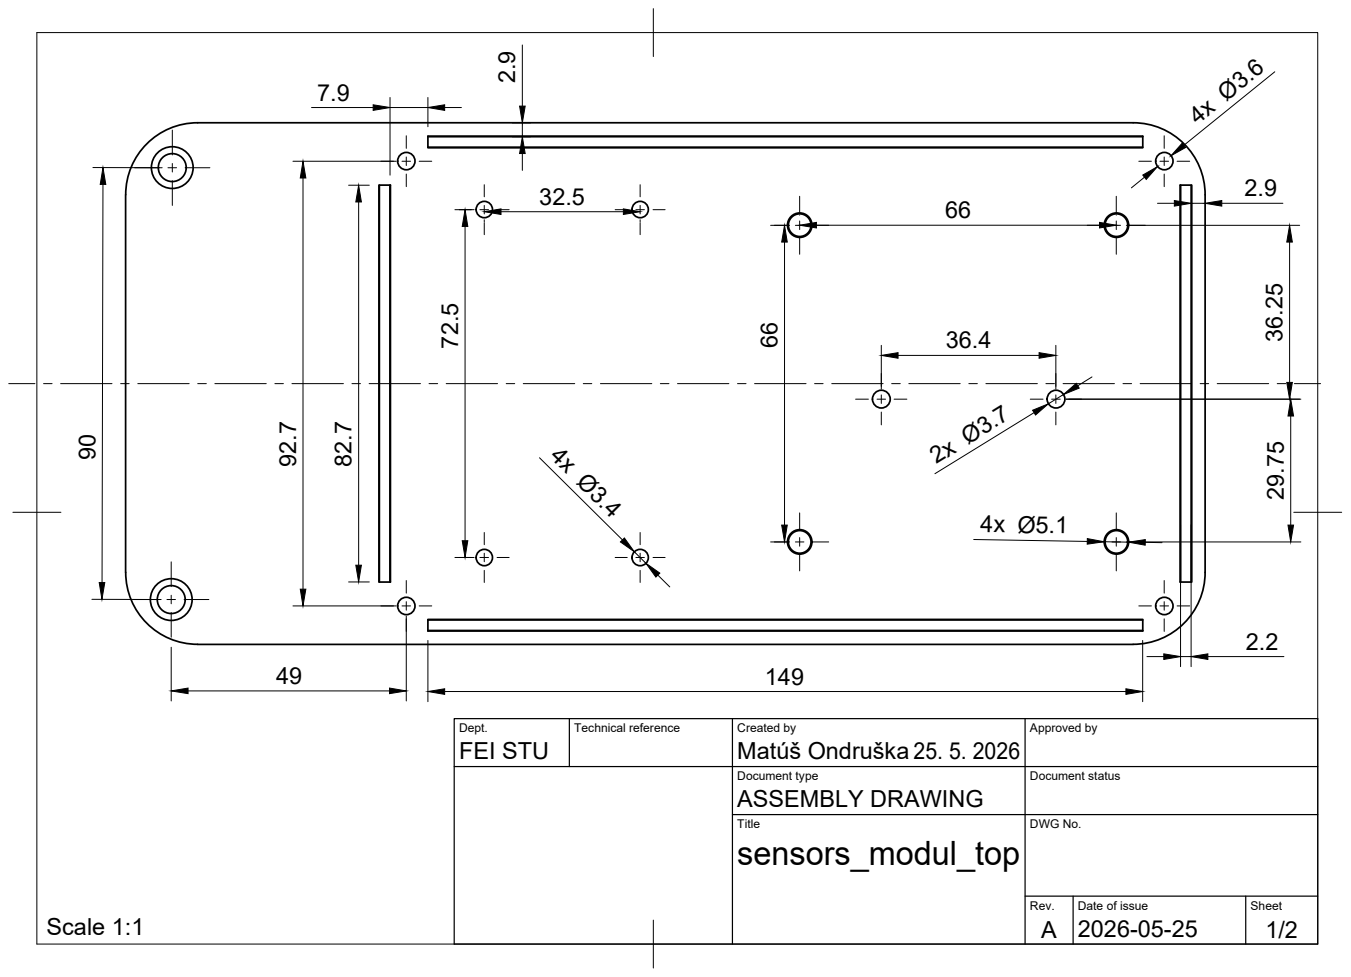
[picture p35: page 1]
Scale 1:1

Dept. FEI STU | Technical reference | Created by Matúš Ondruška 25. 5. 2026 | Approved by

Document type ASSEMBLY DRAWING | Document status

Title sensors_modul_top | DWG No.

Rev. A | Date of issue 2026-05-25 | Sheet 1/2

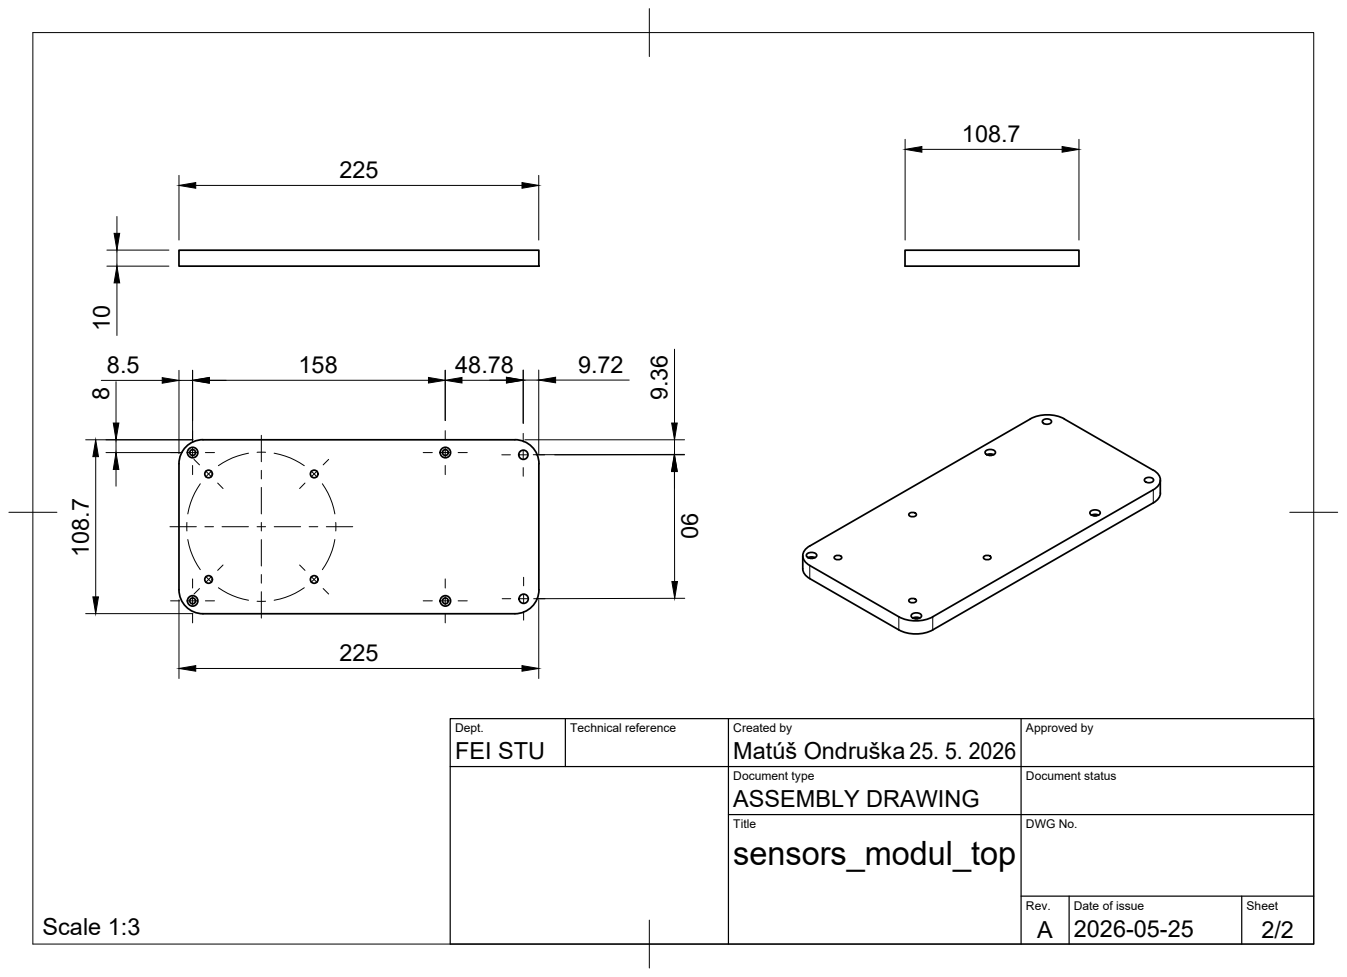
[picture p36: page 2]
FEI STU; Matúš Ondruška 10; Scale 1:3

Dept. | Technical reference | Created by 25. 5. 2026 | Approved by

Document type ASSEMBLY DRAWING | Document status

Title sensors_modul_top | DWG No.

Rev. A | Date of issue 2026-05-25 | Sheet 2/2

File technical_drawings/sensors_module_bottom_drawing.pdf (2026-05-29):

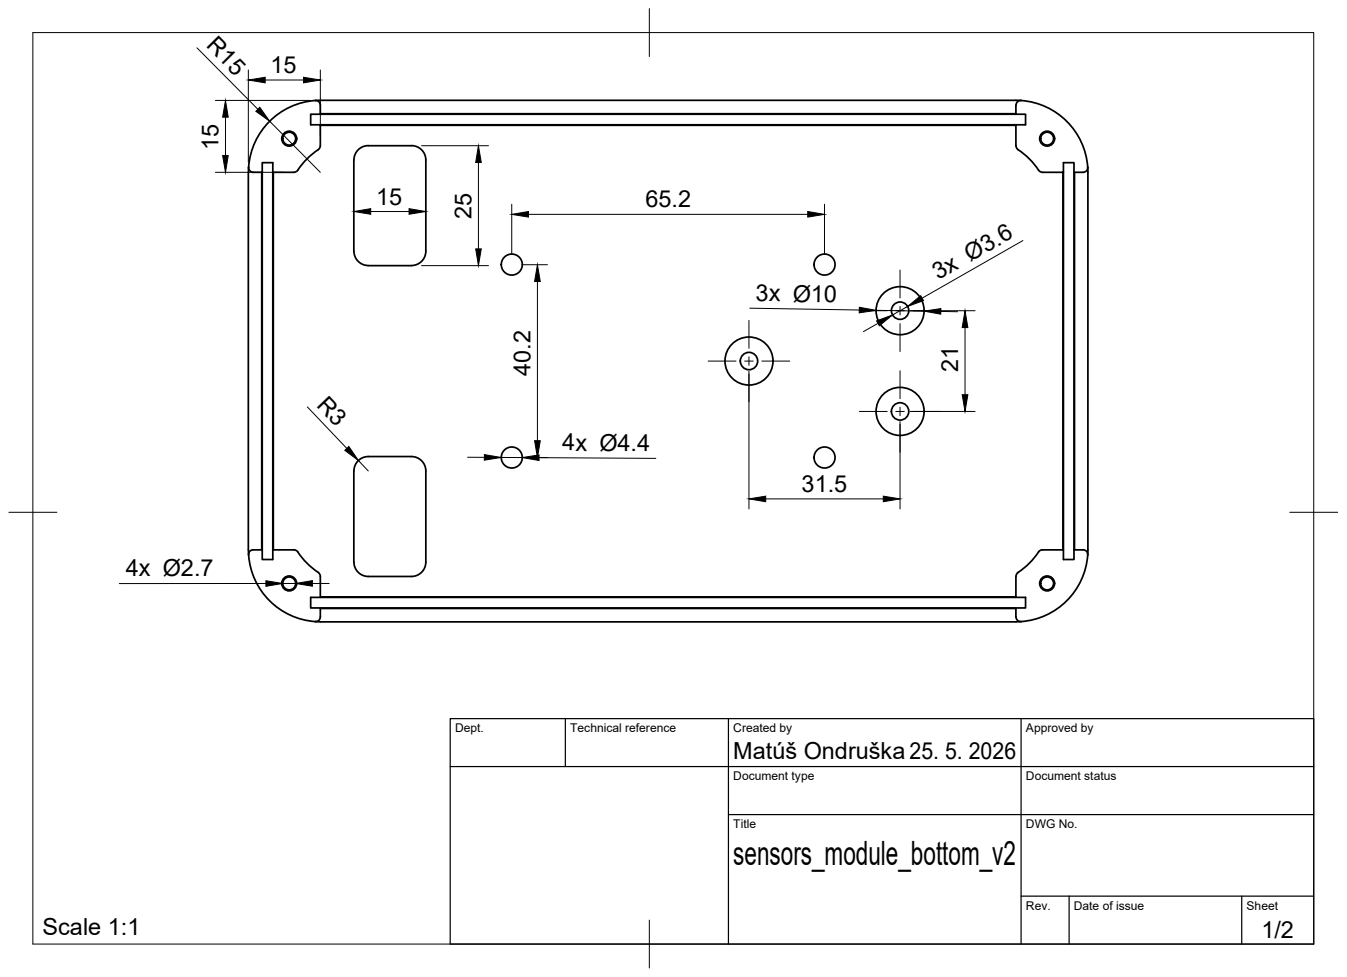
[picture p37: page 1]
Scale 1:1

Dept. | Technical reference | Created by Matúš Ondruška 25. 5. 2026 | Approved by

Document type | Document status

Title sensors_module_bottom_v2 | DWG No.

Rev. | Date of issue | Sheet 1/2

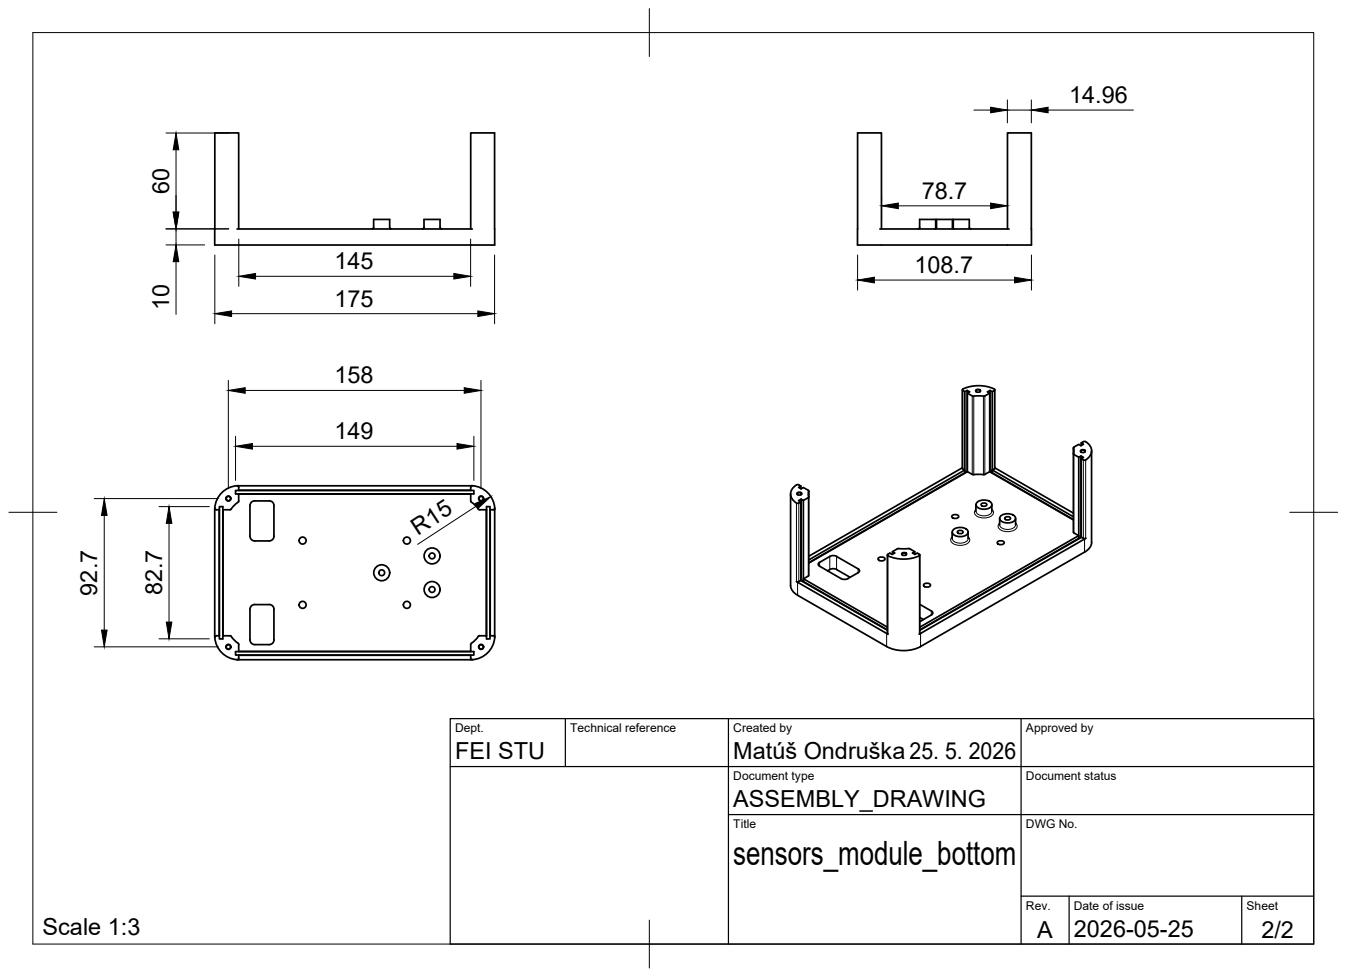
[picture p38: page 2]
Scale 1:3 60 10

Dept. FEI STU | Technical reference | Created by Matúš Ondruška 25. 5. 2026 | Approved by

Document type ASSEMBLY_DRAWING | Document status

Title sensors_module_bottom | DWG No.

Rev. A | Date of issue 2026-05-25 | Sheet 2/2

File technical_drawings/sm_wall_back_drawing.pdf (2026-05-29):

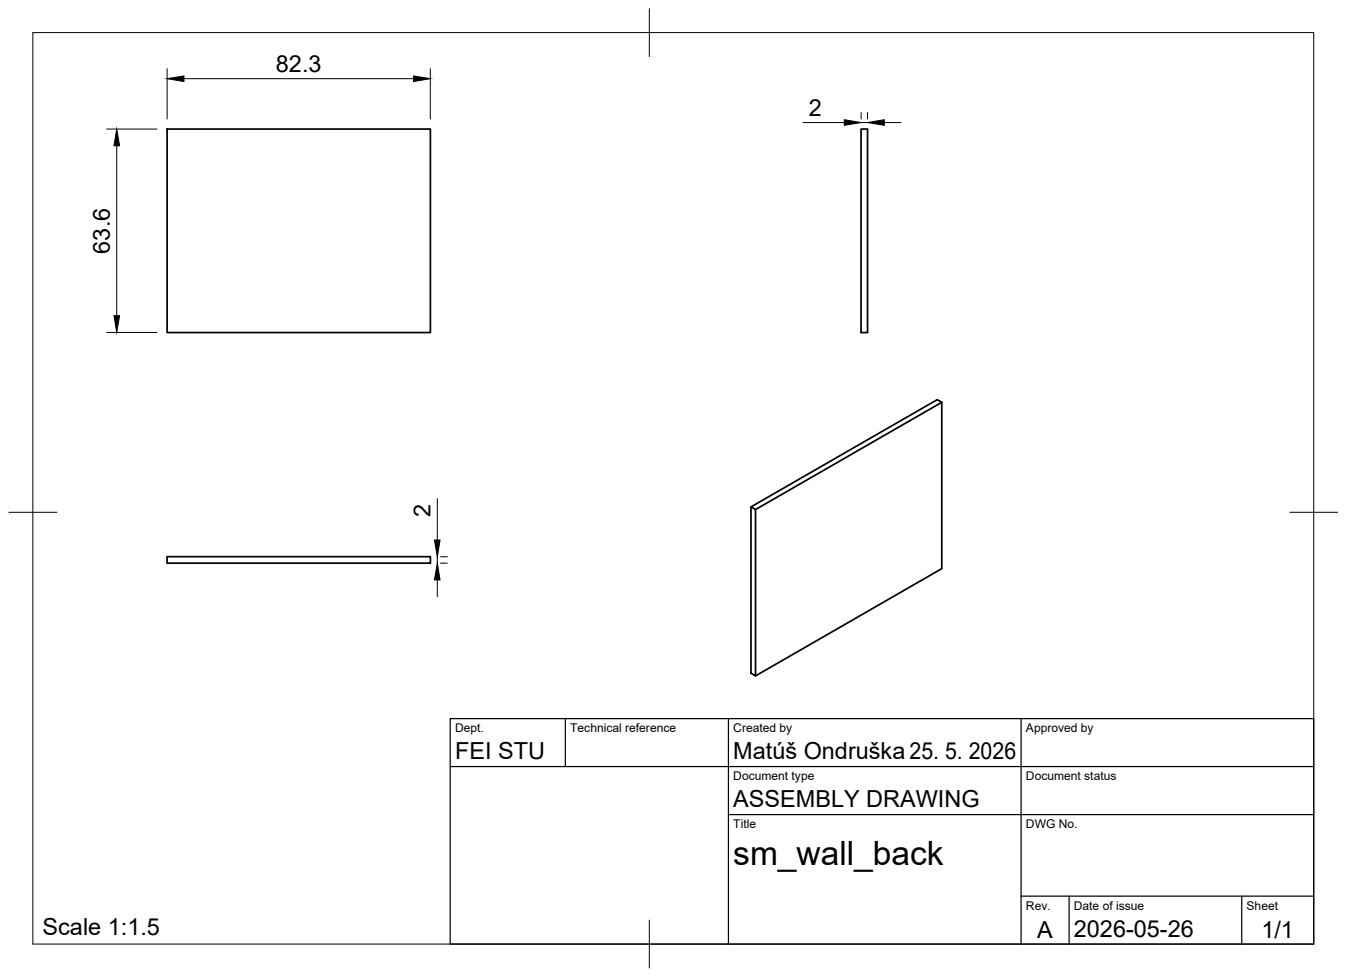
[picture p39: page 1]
Scale 1:1.5

Dept. FEI STU | Technical reference | Created by Matúš Ondruška 25. 5. 2026 | Approved by

Document type ASSEMBLY DRAWING | Document status

Title sm_wall_back | DWG No.

Rev. A | Date of issue 2026-05-26 | Sheet 1/1

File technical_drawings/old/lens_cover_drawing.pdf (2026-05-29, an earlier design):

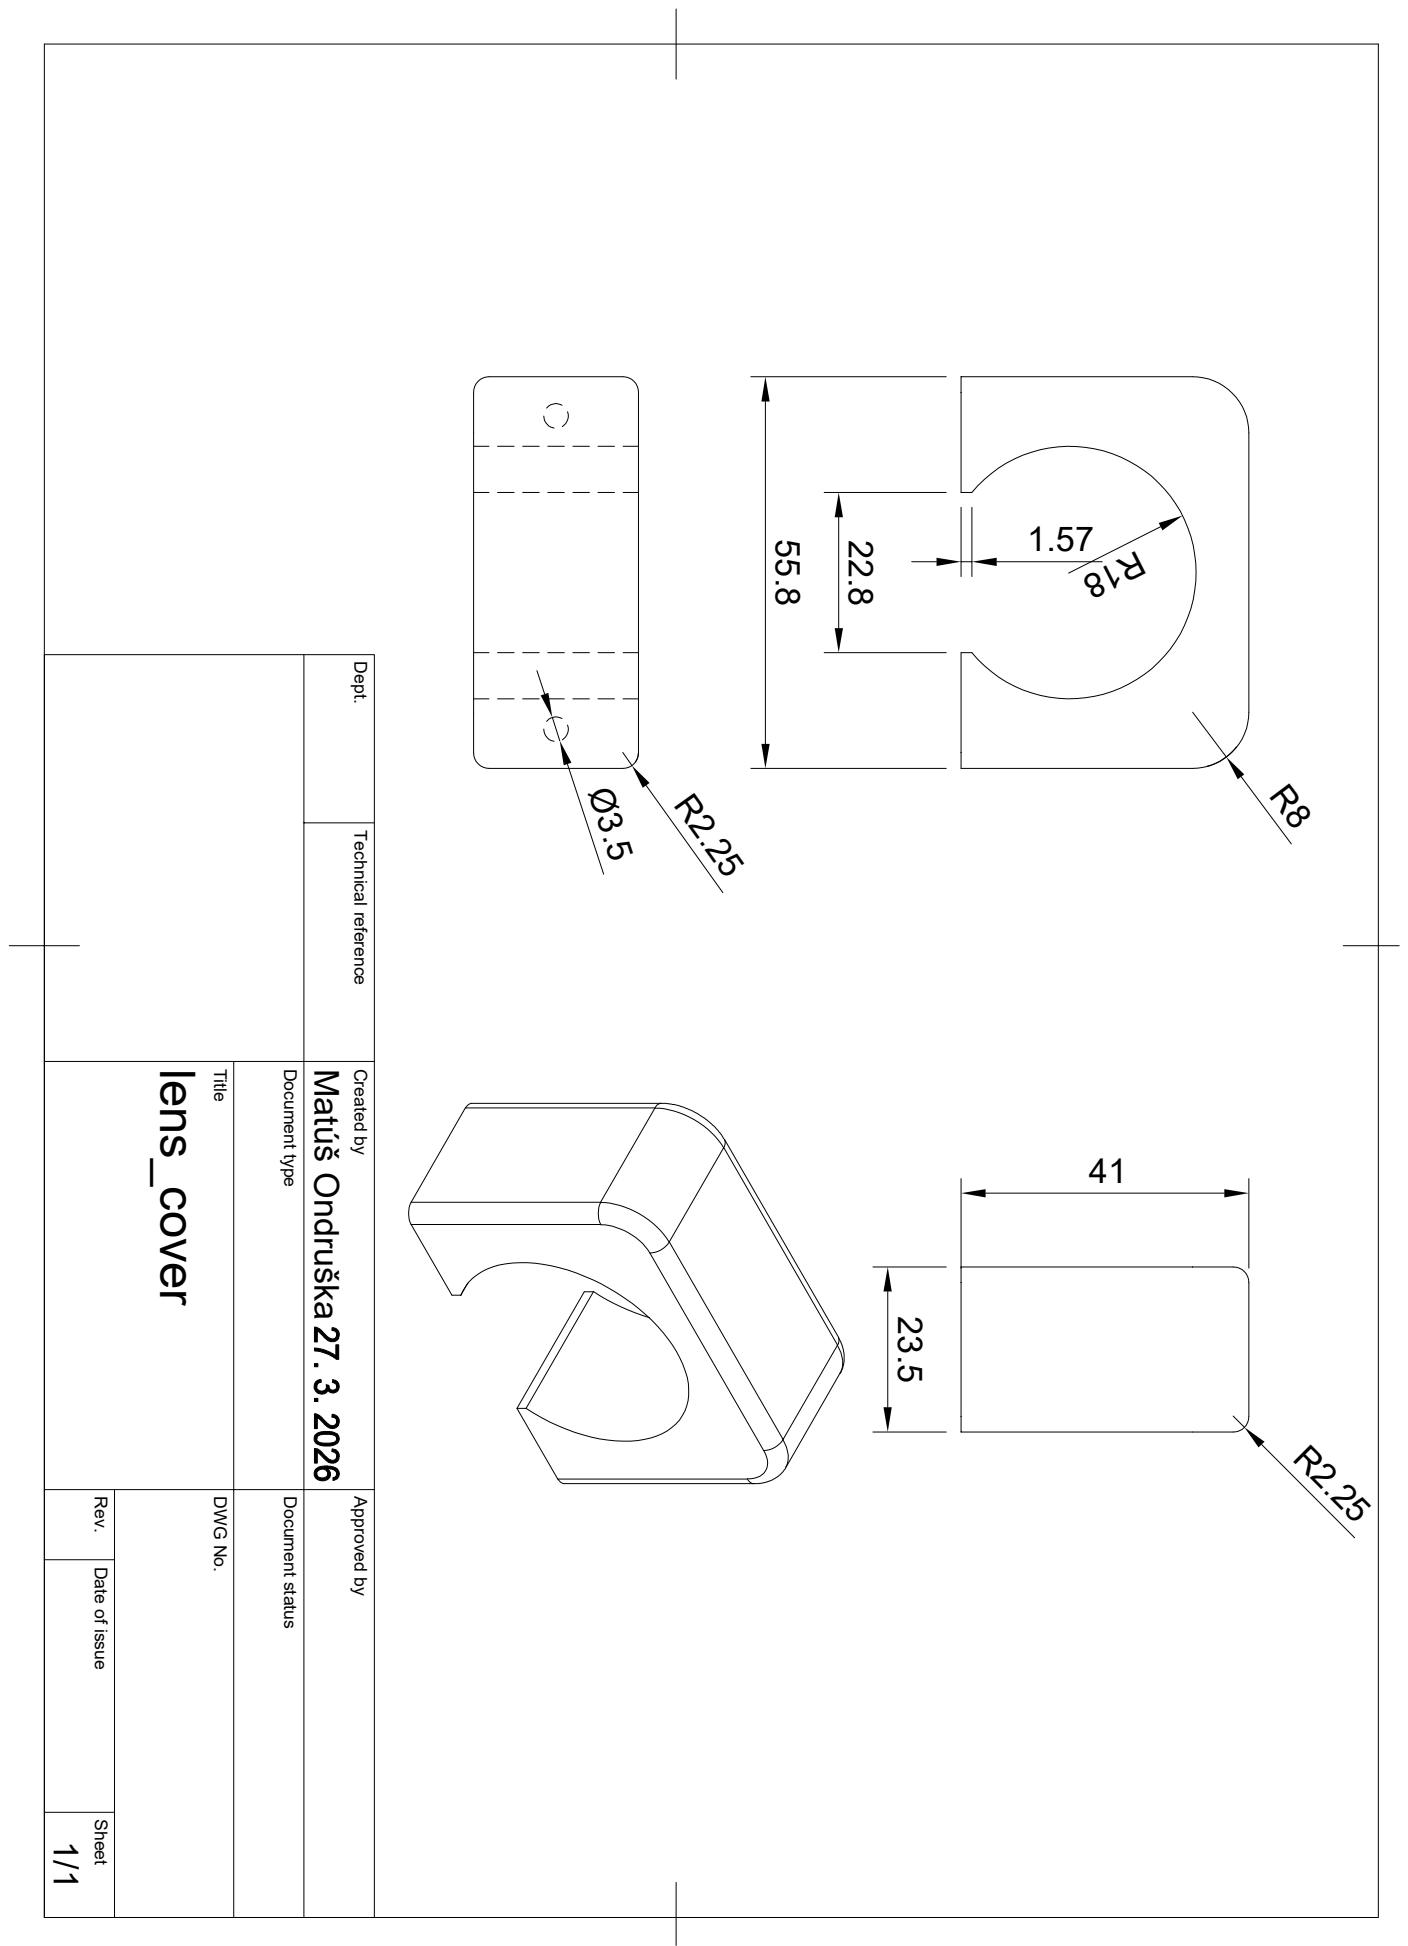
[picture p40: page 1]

Dept. Technical reference Created by Approved by Title DWG No. Document type Document status Rev. Date of issue Sheet 1/1 lens_cover Matúš Ondruška 55.8

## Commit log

2026-03-27 add first prototype parts with drawings
    [Handles.step, lens_cover.step, sensors_modul_top.step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]
2026-04-13 update fasteners list, datasheets, new versions of sensor module parts
    [sensors_modul_top_v2.stl, sensors_modul_top_v3.stl, sensors_module_bottom_v2.stl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]
2026-04-18 add new version of sensor module, create mounting platform, handles and alu profile, assemble all in one assembly
    [Handles.step, bom.csv, handles.step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]
2026-04-26 add .stl files ready to print
    [acu_jetson_case.stl, lens_cover.stl, podstavec.stl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]
2026-05-04 edit acu_jetson_case & sensors_module_top to complete full assembly and update fasteners list
    [acu_jetson_case.stl, bom.csv, handles1.stl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]
2026-05-05 update fasteners list, bom, readme, add extrinsic parameters for IMU LiDAR transform
    [sensors_modul_top_v3.stl]
2026-05-11 Calculate transformations, edit case for jetson and acu
    [acu_jetson_case.stl, handles1.stl, handles2.stl]
2026-05-25 updated README, added images, TODO: update technical drawings
    [acu_jetson_case.stl]
2026-05-27 finalize README, models_img, printable
    [acu_jetson_case.step, acu_jetson_case.stl, handles.step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]
2026-05-27 Clean up extrinsic sensor calibration section
    Removed commented-out extrinsic calibration details from README.
2026-05-27 insert .png instead of math syntax
